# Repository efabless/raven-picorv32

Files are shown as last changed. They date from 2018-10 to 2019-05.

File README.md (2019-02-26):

Raven:  An ASIC implementation of the PicoSoC PicoRV32
===============================================================
Designed by efabless engineering, San Jose, CA

Overview
--------

The purpose of this repository is to provide a completely free
and open-source simulation environment for the Raven chip.  The
Raven chip itself can be found in the efabless IP catalog.  See
https://efabless.com (registration is required to view the IP
catalog.  Regitration is free and validation is not required to
view the catalog contents.  However, validation is required to
use the efabless design environments; e.g., to view the layout
of the raven chip on the Open Galaxy design platform).

The simulation environment matches the reference design in the
efabless IP catalog functionally, and can be used to write
software/firmware that will run on the Raven test board.

The requirements for simulating the Raven chip are:  iverilog
(iverilog.icarus.com), and the RISC-V gcc configured for the
RISC-V options used by the picoRV32 processor design.  The best
way to obtain the correct gcc cross-compiler is to install the
picoRV32 source from github
(https://github.com/cliffordwolf/picorv32).  The Makefile in
the picoRV32 repository automatically downloads and locally
installs the correct gcc cross-compiler.  In this repository,
it is necessary to change the path to gcc in verilog/Makefile
and verilog/*/Makefile to match the local installation.  Once
that is done, cd to the "verilog/" directory and run "make" to
run the simulation test suite.

Documentation on the memory mapping and the SPI slave interface
can be found in the "doc/" directory.

Summary
-------

Raven is using a very popular 32-bit RISC-V core (PicoRV32) developed by Clifford Wolf, a well-known open source champion. The core was previously proven with an FPGA implementation and Raven is the first SoC built with it. The system integrator is our own Tim Edwards, another champion in the open source domain. Included below is a 15s video showing the wakeup, key features and a link to high-level datasheet.

Raven is now published in our marketplace for designers and partner companies to clone and customize starting from a silicon-proven point. It is also published on the RISC-V Foundation’s directory of designs
(https://riscv.org/risc-v-cores)

RAVEN Block Diagram
-------------------

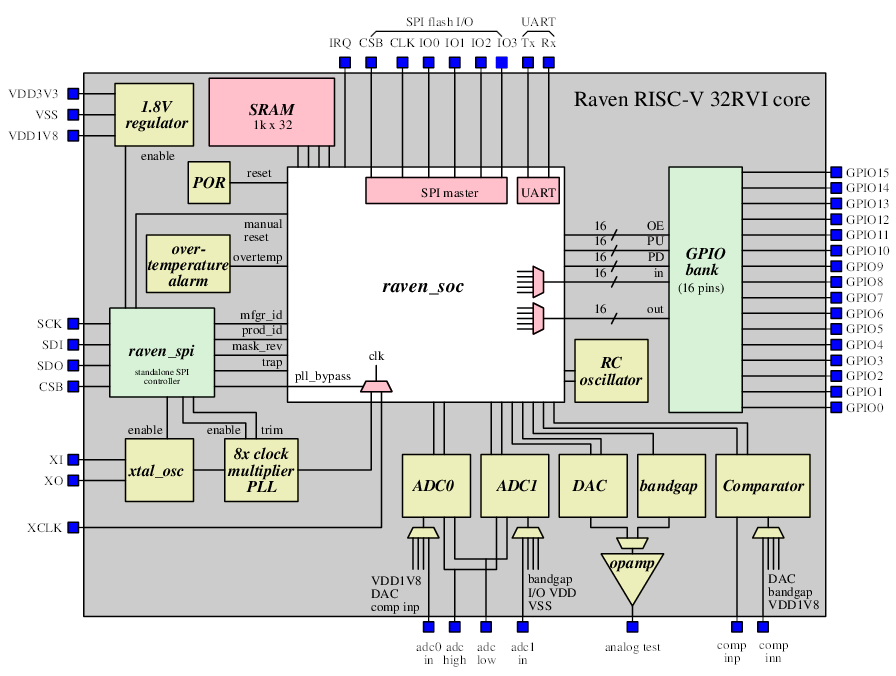
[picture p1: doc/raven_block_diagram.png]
RAVEN-PICORV32


Key Features
------------
* RISC-V CPU (PicoRV32)
* SRAM 32x1024
* 100 MHz clock rate
* Programmable clock source
* 16 channels GPIO
* 2 ADCs
* 1 DAC
* 1 Comparator
* Over-temperature alarm
* 100 kHz RC oscillator
* Programmable functions on GPIO outputs
* Programmable interrupts on GPIO inputs

High-level Datasheet 
---------------------
* https://ef.link/raven

Short Video showing initial wakeup
----------------------------------
* https://ef.link/raven3

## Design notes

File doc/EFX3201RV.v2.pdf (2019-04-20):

# EFX3201RV

## 32-bit RISC-V Microcontroller for Embedded Applications

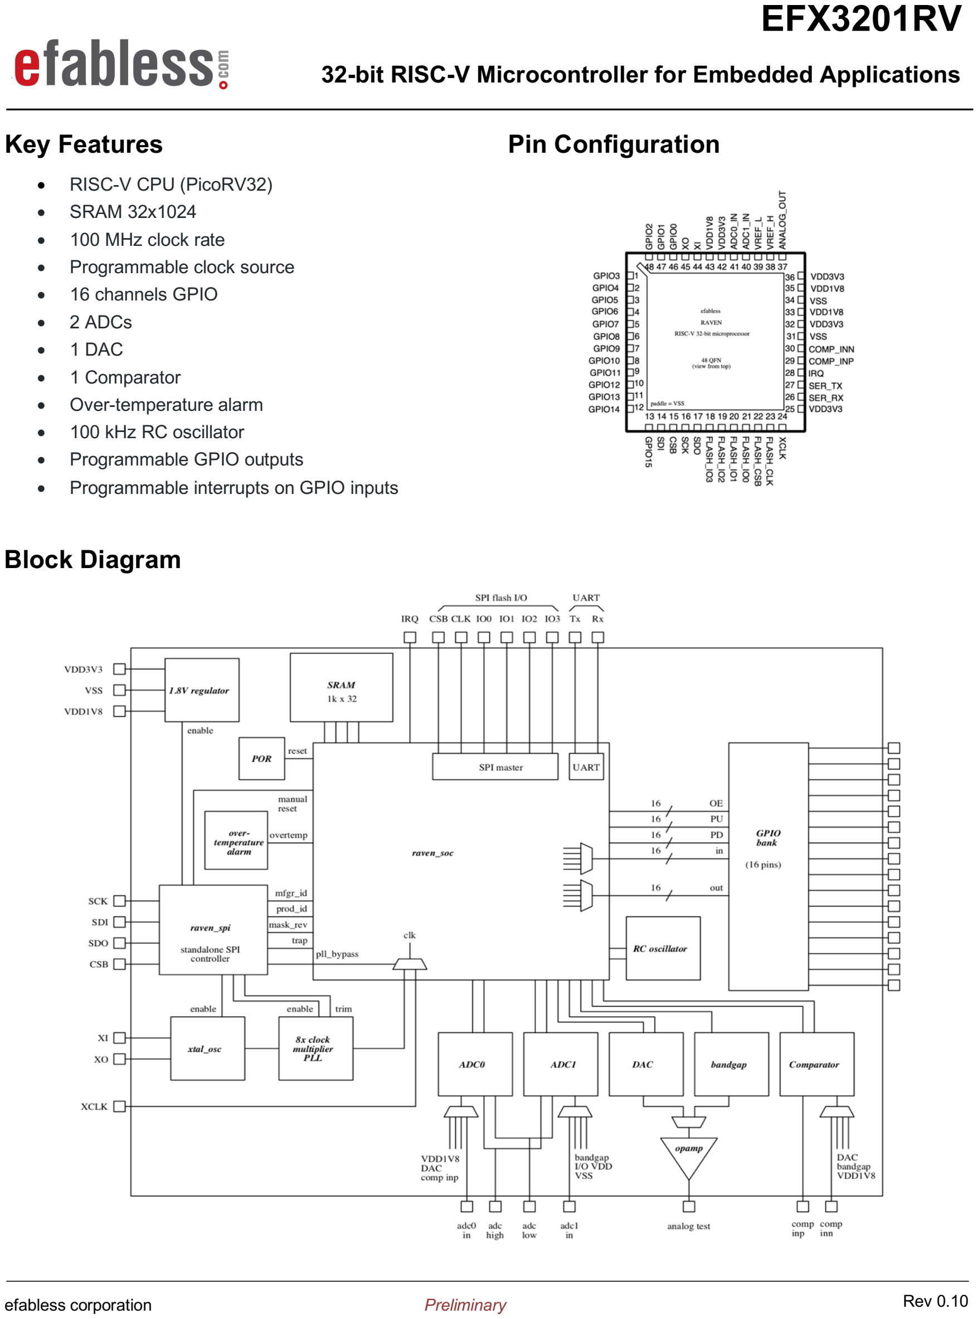
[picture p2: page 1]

efabless corporation | Preliminary

Rev 0.10

# Key Features

### - RISC-V CPU (PicoRV32) - SRAM 32x1024 - 100 MHz clock rate - Programmable clock source - 16 channels GPIO - 2 ADCs - 1 DAC - 1 Comparator - Over-temperature alarm - 100 kHz RC oscillator - Programmable GPIO outputs - Programmable interrupts on GPIO inputs

# Pin Configuration

# Block Diagram

# EFX3201RV

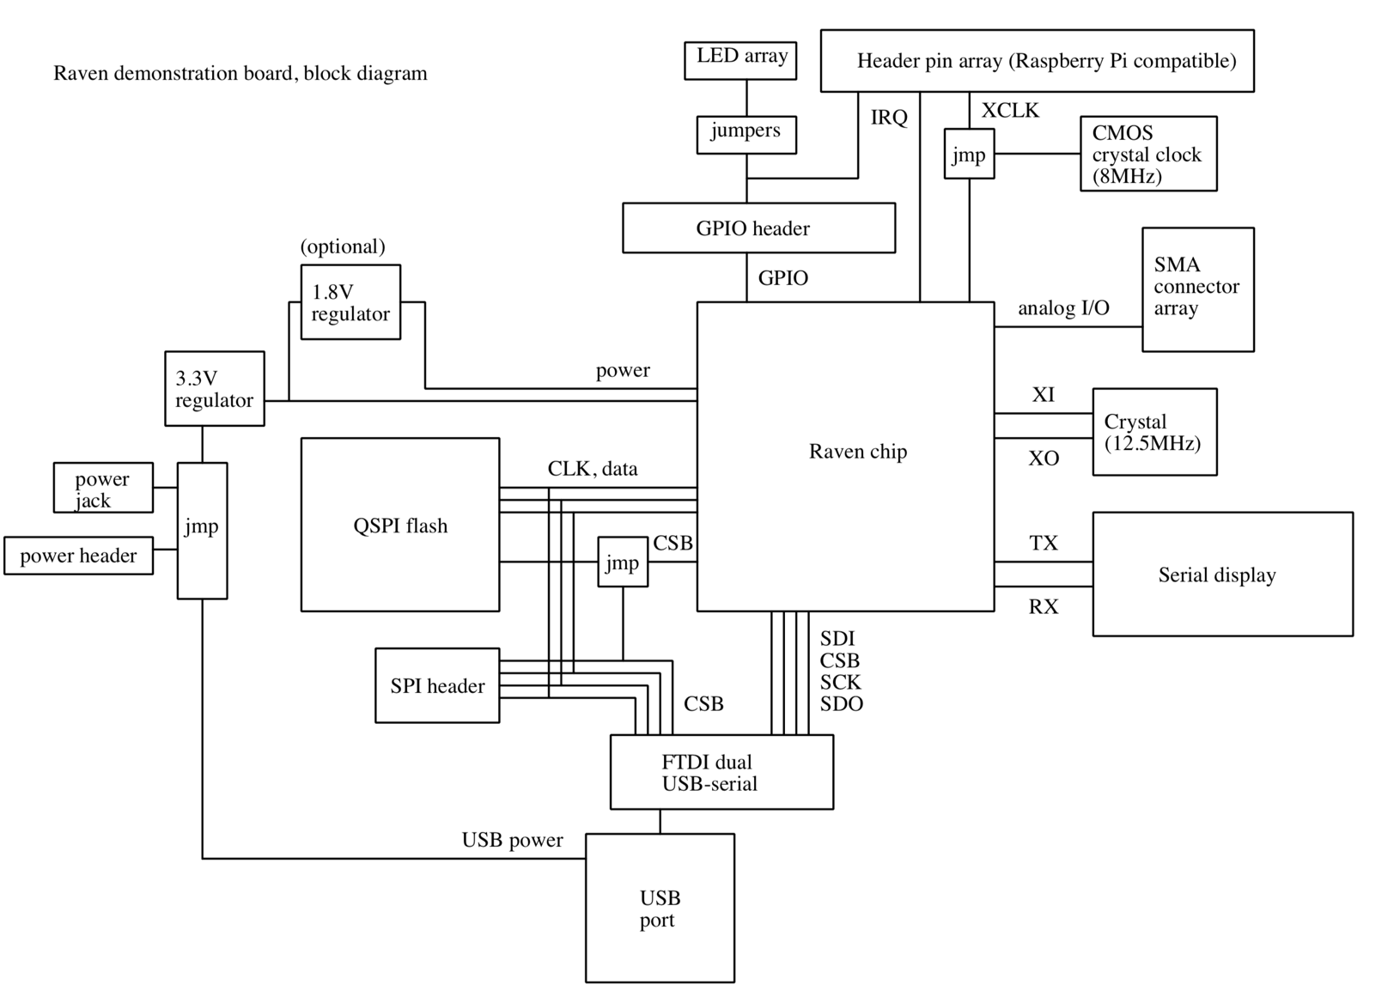
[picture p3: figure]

efabless corporation | Preliminary

## 32-bit RISC-V Microcontroller for Embedded Applications

Rev 0.10

# Raven Development Board

# For more information visit: https://github.com/efabless/raven-picorv32

# Features

1. Can be powered by external supplies, power jack, or USB.
2. Raven SPI programmed through FTDI via USB
3. SMA inputs to analog functions.
4. Serial display for text I/O from Raven chip.
5. Clock from crystal (100MHz onboard), external (8MHz) or data line
6. Match Raspberry Pi header pins with GPIO header pins
7. Split supplies if external 1.8V needed; otherwise chip is powered from 3.3V only. 3. Flash chip programmed through FTDI via USB

SPI flash: Cypress S25FL128 or similar ($2.42 each from Digi-Key). Use the 8-pin SOIC (4 data + clock, select, power, and ground). 3.3V.

Serial display: Use a SparkFun serial-enabled 16x2 LCD ($25), 3.3V, or the 20x4 SerLCD (also $25) (available from Digi-Key). Or the 20x2 SerLCD ($20).

FTDI: Use FT2232H (about $7 for the LQFP package from Digi-Key

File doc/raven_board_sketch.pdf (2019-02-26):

Raven demonstration board, block diagram

Raven chip

Serial display

TX

RX

FTDI dual
USB-serial

SDI
CSB
SCK
SDO

GPIO header

GPIO

USB
port
QSPI flash | CSB

CLK, data

CSB

jumpers

LED array

IRQ | XCLK | CMOS
| | crystal clock (8MHz)

Crystal
(12.5MHz)

XI

XO
power
jack

power header

3.3V
regulator

power

1.8V
regulator | analog I/O

SMA
connector
array

jmp

jmp

SPI header

jmp

USB power

Features:
1. Can be powered from external supplies, power jack, or USB.
2. Split supplies if external 1.8V needed; otherwise chip is powered from 3.3V only.
3. Flash chip programmed through FTDI via USB
4. Raven SPI programmed through FTDI via USB
5. SMA inputs to analog functions.
6. Serial display for text I/O from Raven chip.
7. Clock from crystal (100MHz onboard), external (8MHz) or data line (slow)
8. Match Raspberry Pi header pins with GPIO header pins

SPI flash: Cypress S25FL128 or similar ($2.42 each from Digi-Key). Use the 8-pin SOIC (4 data + clock, select, power, and ground). 3.3V.

FTDI: Use FT2232H (about $7 for the LQFP package from Digi-Key)

Serial display: Use a SparkFun serial-enabled 16x2 LCD ($25), 3.3V, or the 20x4 SerLCD (also $25) (available from Digi-Key). Or the 20x2 SerLCD ($20).

(optional)

Header pin array (Raspberry Pi compatible)

Raspberry-Pi compatibility GPIO header (3.3V)

5V

5V

From USB or power jack

VDD3V3

N/C (I2C)

N/C (I2C) | Ground
| TX
| RX

EXTCLK

Ground

GPIO0 | GPIO1

GPIO2

GPIO3

VDD3V3

SDI

SDO

SCK

Ground

Ground

CSB (Raven)

N/C (2nd SPI CSB)

N/C (I2C EEPROM)

Ground

Ground

Ground

Ground

GPIO4

GPIO5

GPIO6

GPIO7

GPIO8

GPIO9

GPIO10

GPIO11

GPIO13

GPIO14

GPIO15

GPIO12

N/C (I2C EEPROM)

NOTES:

Generally, the GPIO line up with similar channels on the Raspberry Pi board. The GCLK on the Pi is connected to the Raven external clock input. The I²C lines are not connected. The Raven SPI is connected to the Pi SPI lines.

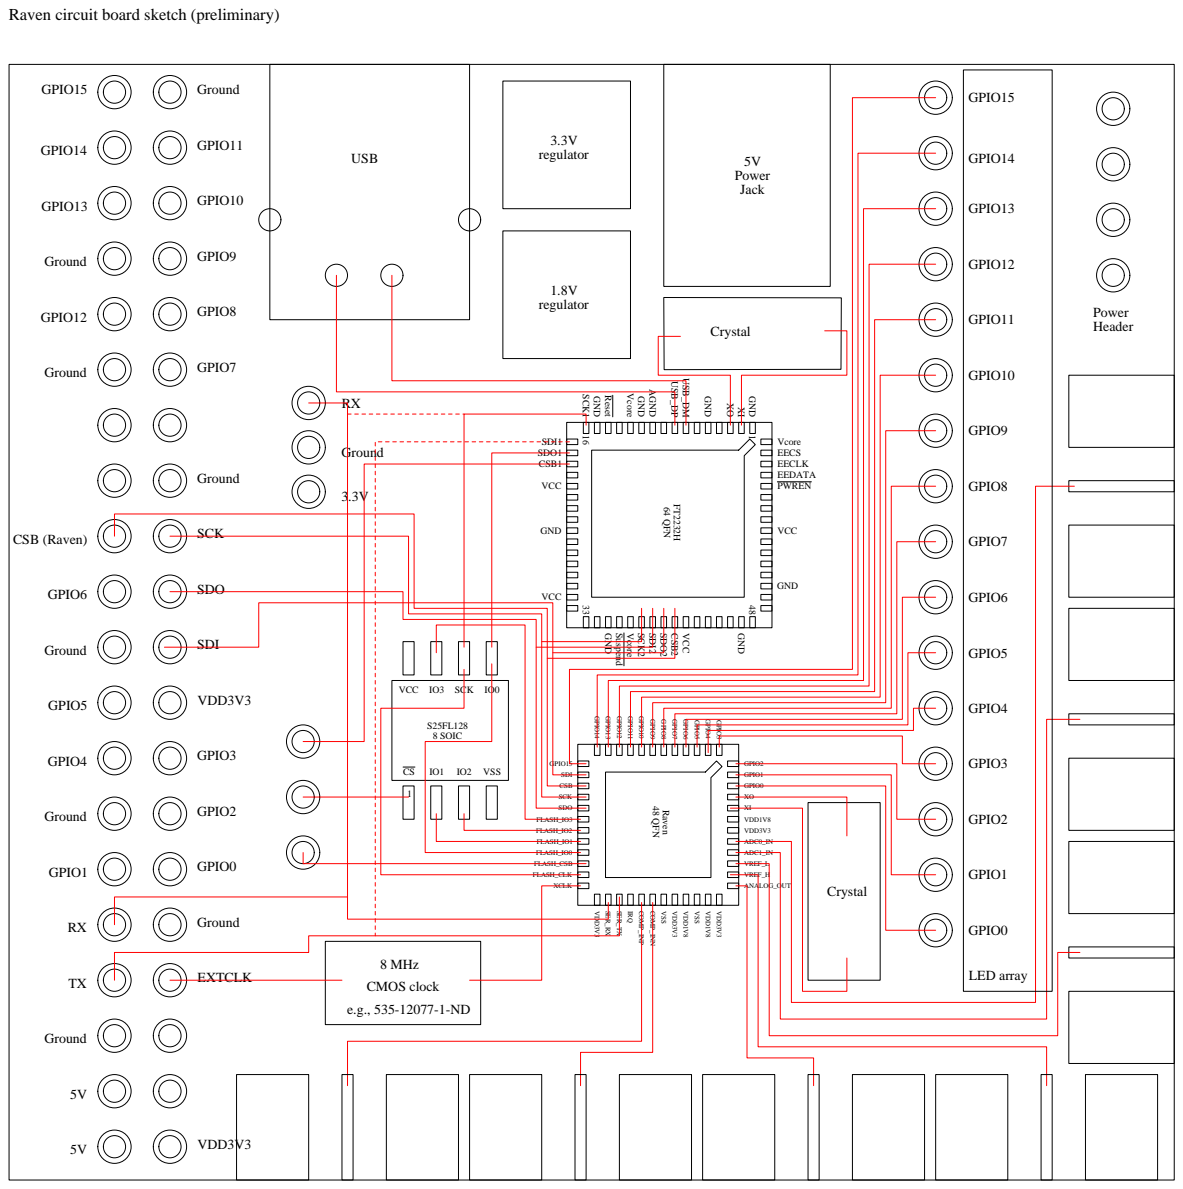
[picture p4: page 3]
Raven; 48 QFN; GPIO15 SDI CSB SCK SDO FLASH_IO3 FLASH_IO2 FLASH_IO1 FLASH_IO0 FLASH_CSB FLASH_CLK XCLK; VDD3V3; SER_RX; SER_TX; IRQ; COMP_INP; COMP_INN; VSS; VDD1V8; GPIO2 GPIO1 GPIO0 XO XI VDD1V8 VDD3V3 ADC0_IN ADC1_IN VREF_L VREF_H ANALOG_OUT; GPIO9; GPIO8; GPIO7; GPIO6; GPIO5; GPIO4; GPIO3; GPIO14; GPIO13; GPIO12; GPIO11; GPIO10; EXTCLK; Ground; GPIO0; GPIO2; SDI; SDO; SCK; GPIO1; CSB (Raven); GPIO15; 64 QFN; 1 GND; GND; VCC; AGND; Reset; EECS EECLK EEDATA PWREN; Suspend; SCK1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

Raven circuit board sketch (preliminary)

Vcore Vcore Vcore

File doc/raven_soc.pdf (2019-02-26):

Raven SoC—A PicoSoC implementation in X-Fab XH018

Raven Memory Mapped I/O

0x02 00 00 00

Address (bytes) | Function
0x02 00 00 04 | UART clock divider select (system clock freq. / baud rate)
0x02 00 00 08 | UART data (returns 0xffffffff if receiver buffer is empty)

SPI master config

0x00 00 00 00 | Flash SPI / overlaid SRAM (1k words) start of memory block
0x00 10 00 00 | Reset vector
0x01 00 00 00 | Flash SPI start of memory block

0x03 00 00 00

bit 31 MEMIO enable (reset = 1) 0 = bit-bang mode bit 22 DDR enable
bit 21 QSPI enable
bit 20 CRM enable
bits 19-16 Read latency cycles
bits 11-8 I/O output enable bits (bit bang mode) bit 5 Chip select line (bit bang mode)
bit 4 Serial clock line (bit bang mode)
bits 3-0 Data bits (bit bang mode)

GPIO input/output data (lower 16 bits)
0x03 00 00 04 | GPIO input enable (1 = input, 0 = output)
0x03 00 00 08 | GPIO pullup enable (1 = pullup, 0 = none)
0x03 00 00 0c | GPIO pulldown enable (1 = pulldown, 0 = none)
0x03 00 00 10 | ADC0 enable (low bit 1 = enabled, 0 = disabled)
0x03 00 00 14 | ADC0 data (10 bits) read-only
0x03 00 00 18 | ADC0 done (low bit 1 = done, 0 = busy) read-only
0x03 00 00 1c | ADC0 start conversion (low bit 1 = convert, 0 = reset)
0x03 00 00 20 | ADC0 clock source (low 2 bits)
| 0 =
| 1 =
| 2 =
| 3 =
0x03 00 00 24 | ADC0 input source (low 2 bits)
| 0 =
| 1 =
| 2 =
| 3 =
0x03 00 00 30 | ADC1 enable (low bit 1 = enabled, 0 = disabled)
0x03 00 00 34 | ADC1 data (10 bits) read-only
0x03 00 00 38 | ADC1 done (low bit 1 = done, 0 = busy) read-only
0x03 00 00 3c | ADC1 start conversion (low bit 1 = convert, 0 = reset)
0x03 00 00 40 | ADC1 clock source (low 2 bits)
| 0 =
| 1 =
| 2 =
| 3 =
0x03 00 00 44 | ADC1 input source (low 2 bits)
| 0 =
| 1 =
| 2 =
| 3 =

external pin
VDD1V8
DAC
comparator P input

external pin

VDD3V3
VSS

bandgap

RC osc
SPI SCK
Xtal clock
XCLK pin

RC osc
SPI SCK
Xtal clock
XCLK pin

Program to run starts here.

16 bits of general-purpose digital

ADC can be manually clocked via the SPI SCK or XCLK pins, or automatically clocked at the rate of the crystal or the RC oscillator.

ADC normally reads the value of an external pin, but for testing can be set to read the internal values of the core power supply, DAC, or the comparator P input pin.

ADC can be calibrated by setting input to the 3.3V power supply and ground, and can be used to read the bandgap voltage.

Address (bytes) | Function
0x03 00 00 54 | DAC value (10 bits)
0x03 00 00 50 | DAC enable (low bit 1 = enabled, 0 = disabled)
0x03 00 00 60 | Comparator enable (low bit 1 = enabled, 0 = disabled)
0x03 00 00 64 | Comparator N input source (low 2 bits)
| 0 = 1 = 2 = 3 =
0x03 00 00 68 | Comparator P input source (low 2 bits)
| 0 = 1 = 2 = 3 =
0x03 00 00 6c | Comparator output destination (low 2 bits)
| 0 = 1 =
0x03 00 00 70 | RC oscillator enable (low bit, 1 = enabled, 0 = disabled)
0x03 00 00 74 | RC oscillator output destination (low 2 bits)
| 0 =
| 1 =
| 2 =
| 3 =
0x03 00 00 80 | SPI configuration byte (low 8 bits) (read-only)
| Value currently fixed at zero
0x03 00 00 84 | SPI master enables (low 2 bits) (read-only)
| bit 0 = 1.8V regulator enable
| bit 1 = Crystal oscillator enable
0x03 00 00 88 | SPI PLL config (low 7 bits) (read-only)
| bit 0 = PLL current bias enable
| bit 1 = PLL VCO enable
| bit 2 = PLL CP enable
| bits 3-6 = PLL frequency trim
0x03 00 00 8c | SPI manufacturer ID (low 12 bits) ( = 0x0456) (read-only)
0x03 00 00 90 | SPI product ID (low 8 bits) ( = 0x02) (read-only)
0x03 00 00 94 | SPI mask revision (low 4 bits) ( = 0x00) (read-only)
0x03 00 00 a0 | Crystal output destination (low 2 bits)
| 0 =
| 1 =
| 2 =
| 3 =
0x03 00 00 98 | SPI PLL bypass mode (low bit) (read-only)

external pin
DAC
bandgap
VDD1V8

external pin

2 =
3 =

GPIO(0)
GPIO(1)
IRQ(9)

none

GPIO(2)
GPIO(3)

none

GPIO(4)

GPIO(5)
GPIO(6)
GPIO(7)

none

DAC
bandgap
VDD1V8

Raven SoC—A PicoSoC implementation in X-Fab XH018

Raven Memory Mapped I/O (continued)

Comparator can have one input set to a known internal value, either the DAC output, the bandgap voltage, or the core supply voltage.

Comparator output can be seen directly
on GPIO 0 or 1, or used to trigger CPU interrupt IRQ 9. GPIOs 0 and 1 cannot be used for general-purpose I/O when selected for comparator output.

RC oscillator output can be passed directly to GPIO 2, 3, or 4. These cannot be used as general-purpose I/O when selected for RC oscillator output.

Most bits of the SPI register map are mirrored to memory locations and can be read by the CPU. These bits are read-only and cannot be modified.

The crystal oscillator clock (before the PLL) can be coupled to any of GPIO pins 5, 6, or
7. These GPIOs cannot be used as general-purpose I/O when selected for crystal oscillator clock output.

Address (bytes) | Function
0x03 00 00 a4 | PLL clock output destination (low 2 bits) 0 = 1 = 2 = 3 =
0x03 00 00 a8 | Trap output destination (low 2 bits) 0 = 1 = 2 = 3 =
0x03 00 00 b0 | IRQ 7 input source (low 2 bits) 0 = 1 = 2 = 3 =
0x03 00 00 b4 | IRQ 8 input source (low 2 bits) 0 = 1 = 2 = 3 =
0x03 00 00 c0 | Analog output select (low bit) 0 = DAC 1 =

0x03 00 00 c4

0x03 00 00 c8 | Analog output enable (low bit, 1 = enabled, 0 = disabled) Analog output bias enable (low bit, 1 = enabled, 0 = disabled)
0x03 00 00 d0 | Bandgap enable (low bit, 1 = enabled, 0 = disabled) bandgap

none
GPIO(8)
GPIO(9)
GPIO(10)

none
GPIO(11)
GPIO(12)
GPIO(13)

GPIO(0)

none

none

GPIO(1)
GPIO(2)

GPIO(3)
GPIO(4)
GPIO(5)

Raven SoC—A PicoSoC implementation in X-Fab XH018

Raven Memory Mapped I/O (continued)

The PLL clock (crystal oscillator clock multiplied up by 8 times) can be viewed on any of GPIO 8, 9, or 10. These GPIOs cannot be used as general-purpose I/O when selected for PLL clock output. It is unlikely that a full-speed (100MHz) clock will be able to toggle the GPIO at full swing, but a slower clock (5 MHz crystal / 40 MHz core clock) should have a proper output.

The CPU fault state (trap) can be viewed at GPIO 11, 12, or 13, as a way to monitor the CPU trap externally.

The GPIO inputs can be used as IRQ event sources and passed to the CPU through IRQ channels 7 and 8. When used as IRQ sources, the corresponding GPIO channel must be first configured as an input.

A single op-amp configured as an analog buffer can be selected to mirror the analog DAC output or the bandgap output.

0x03 00 00 e0 | Over-temperature alarm enable (low bit, 1 = enabled, 0 = disabled)
0x03 00 00 e4 | Over-temperature value (low bit, read-only)
0x03 00 00 e8 | Over-temperature destination (low 2 bits)
| 0 = 1 = 2 = 3 = none GPIO(14) GPIO(15) IRQ(10) The over-temperature sensor triggers at 133 degrees C. It can be viewed at GPIO 14 or 15, or used as an IRQ source to the CPU.

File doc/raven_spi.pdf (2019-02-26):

msb | lsb
Register
Address
0x00 | SPI status and control | unused/undefined for now.
0x01 | mask revision (= 0x0) | manufacturer_ID[11:8] (= 0x4) | read-only
0x02 | manufacturer_ID[7:0] (currently undefined, = 0x56) | | read-only
0x03 | product_ID (= 0x02) | | read-only
0x04 | enable | 1.8V regulator enable | PLL VCO enable | PLL CP enable | PLL trim[3:0] xtal osc. | default 0xf0
0x05 | unused | PLL bypass | default 0x00
0x06 | unused | CPU IRQ | default 0x00
0x07 | unused | CPU reset | default 0x00
0x08 | unused | CPU trap | read-only
0x09 | undefined, use TBD | | all undefined registers read 0x00
7 | 6 | 5 | 4 | 3 | 2 | 1 | 0 | comments

Raven rev 0 SPI register definition:

January 4, 2018

NOTES: These registers access values that are impossible to reach using the CPU.
(1) The crystal oscillator drives the CPU clock, so it cannot be turned on and off from inside the CPU. By default it is enabled.
(2) The 1.8V regulator supplies power to the CPU, so it cannot be disabled from the CPU. By default it is enabled.
(3) The PLL generates the high-speed clock from the low-speed crystal, acting as an 8x clock multiplier. By default it is enabled, and has zero trim.
(4) PLL bypass allows the CPU to completely bypass the crystal and PLL and be driven directly by a signal on the XCLK pin.
(5) CPU IRQ is a dedicated interrupt that can be applied to the CPU from the SPI for test purposes.
(6) CPU reset allows the CPU to be reset independently of the power-on-reset circuit.
(7) CPU trap is the fault signal from the CPU. If raised, then the CPU has encountered a bad instruction and has stopped.

Under normal working conditions, the SPI should not need to be accessed unless it is to adjust the clock speed of the CPU. All other functions are purely for test and debug.

All values in the SPI registers are exported to the CPU and can be viewed (read-only) in memory-mapped space (see the memory map documentation).

Errata (updated February 2019):

1. The bits of register 0x04 read as shown above but must be written in the reverse order of bits.
2. The PLL CP enable is nonfunctional as the corresponding output bit in the SPI block is hard-coded to force logic 1 always.

SPI protocol definition

Table 1: Command words
00000000 | No operation
10000000
01000000 | Write in streaming mode
| Read in streaming mode
11000000 | Simultaneous Read/Write in streaming mode
10nnn000

All input is in groups of 8 bits. Each byte is input msb first.

The first transferred byte is the command word, interpreted according to Table 1 below.

CSB pin must be low to enable an SPI transmission. Data are clocked by pin SCK, with data valid on the rising edge of SCK. Output data are received on the SDO line. SDO is held high-impedance when CSB is high and at all times other than the transfer of data bits on a read command. SDO outputs become active on the falling edge of SCK, such that data are written and read on the same SCK rising edge.
After CSB is set low, the SPI is always in the "command" state, awaiting a new command.

Addresses are read in sequence from lower values to higher values.
Therefore groups of bits larger than 8 should be grouped such that the lowest bits are at the highest address. Any bits additional to an 8-bit boundary should be at the lowest address.
Data are captured from the register map in bytes on the falling edge of the last SCK before a data byte transfer. Multi-byte transfers should ensure that data do not change between byte reads.

01nnn000
11nnn000

Write in n-byte mode (up to 7 bytes).
Read in n-byte mode (up to 7 bytes).
Simultaneous Read/Write in n-byte mode (up to 7 bytes).

All other words are reserved and act as no-operation if not defined by the SPI slave module.

The two basic modes of operation are "streaming mode" and "n-byte mode". In "streaming mode" operation, data are sent or received continuously, one byte at a time, with the internal address incrementing for each byte. Streaming mode operation continues until CSB is raised to end the transfer.

Every command sequence requires one command word (8 bits) followed by one address word (8 bits) followed by one or more data words (8 bits each), according to the data transfer modes defined below.

In "n-byte mode" operation, the number of bytes to be read and/or written is encoded in the command word, and may have a value from 1 to 7 (note that a value of zero implies streaming mode). After n bytes have been read and/or written, the SPI returns to waiting for the next command. No toggling of CSB is required to end the command or to initiate the following command.

Raven rev0 efabless, inc.

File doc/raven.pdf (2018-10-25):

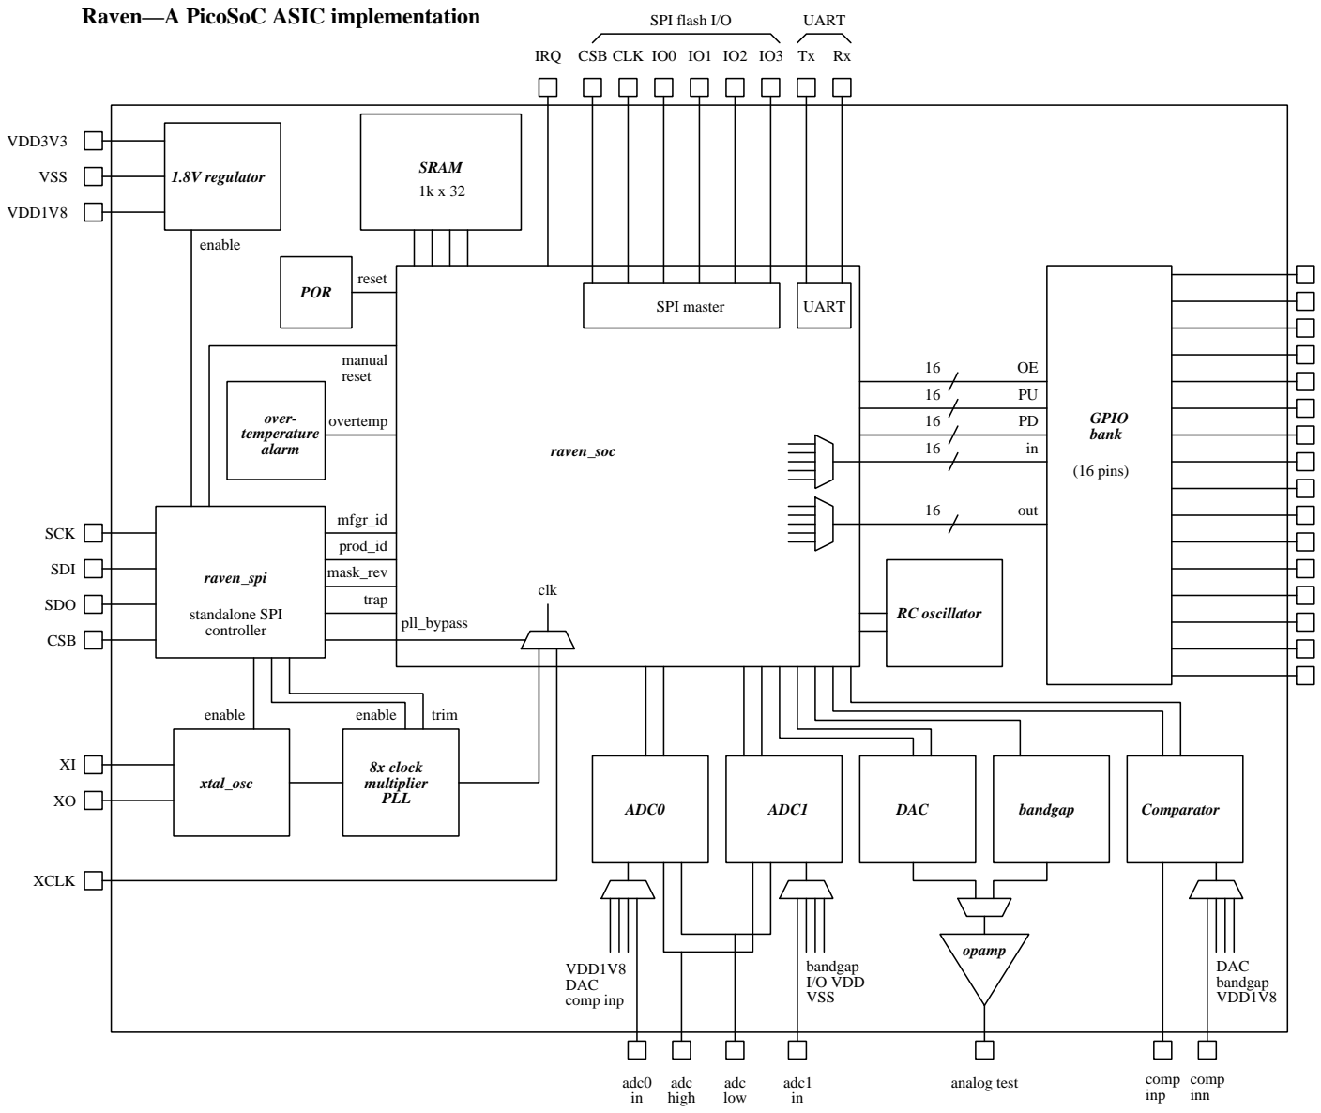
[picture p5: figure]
Raven—A PicoSoC ASIC implementation; raven_soc; GPIO bank; out; (16 pins); raven_spi; SCK; SDI; SDO; CSB; xtal_osc; 1.8V regulator; VDD3V3; VDD1V8; VSS; 8x clock multiplier PLL; XCLK; pll_bypass; clk; enable; trim; mfgr_id; prod_id; mask_rev; over- temperature alarm; overtemp; ADC0; ADC1; DAC; Comparator; RC oscillator; POR; reset; manual reset; bandgap; opamp; adc0; analog test; adc high; adc low; adc1 in; comp inp; comp inn; VDD1V8 DAC comp inp; bandgap I/O VDD VSS; DAC bandgap VDD1V8; IRQ; trap; SRAM; SPI flash I/O; UART; standalone SPI controller; CSB CLK IO0 IO1 IO2 IO3; SPI master

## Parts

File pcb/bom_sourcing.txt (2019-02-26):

eFabless Raven PicoRV32 development/demonstration board
---------------------------------------------------------
U1	efabless Raven PicoRV32
	QFN48
	(custom ASIC, provided)

U2	FT2232H		Dual USB/serial interface driver
	FTDI
	64 LQFP package
	Digi-key 768-1024-1-ND		$6.71 (total $6.71)

U3	93LC46 SPI EEPROM
	MicroChip Technology
	8 TSSOP
	Digi-key 93LC46B-I/ST-ND	$0.27	(total $0.27)

U4	S25FL128
	128M SPI Flash SRAM
	Cypress Semiconductor
	8 SOIC
	Digi-key 428-4051-ND		$2.46	(total $2.46)

U5	AP7333-33SAG-7	3.3V LDO, 0.3A
	Diodes, Inc. 
	SOT23-3
	Digi-key AP7333-33SAG-7DICT-ND	$0.48	(total $0.48)

U6	AP7333-18SAG-7	1.8V LDO, 0.3A
	Diodes, Inc. 
	SOT23-3
	Digi-key AP2125N-1.8TRG1DICT-ND  $0.49	(total $0.49)
	NOTE:  This part is optional.

X1	Crystal, 12MHz, 18pF
	ECS, Inc.
	SMD HC-49USX CSM-7X ECS-120-18-5PX-TR
	Digi-key XC1289CT-ND	 	$0.21	(total $0.21)

X2	Crystal 12.5MHz, 18pF
	TXC Corp.
	Crystal 12.5MHz 18pF SMD
	Digi-key 887-2416-1-ND		$0.43	(total $0.43)

X3	CMOS Crystal oscillator, 8MHz
	Abrocon LLC ASCO-8.000MHZ-EK-T3
	Digi-key 535-12077-1-ND		$1.86	(total $1.86)

J1	4x2 header, 0.1" spacing
	(see below *)

J2-J5	3-pin headers, 0.1" spacing (4x)
	(see below *)

J6	4-pin connector
	Molex, Inc. 0022232041  4 position 0.1" spacing header
	Digi-key WM4202-ND		$0.37	(total $0.37)
	
J7	2.5mm power jack
	CUI, Inc.  PJ002B
	Digi-key CP-002B-ND	 	$0.92	(total $0.92)

J8	USB type B 4-position connector
	TE Connectivity 292304-1
	Digi-key A31725-ND	 	$1.92	(total $1.92)

J9	17x2 test header, 0.1" spacing, unpopulated
	(no component installed)

J10	20x2 header, 0.1" spacing
	(see below *)

J11-J12	3-pin headers, 0.1" spacing (2x)

*	All headers from one break-off header 2x36 position (gold)
	3M 961272-6404-AR
	Digi-key 3M9466-72-ND		$4.60	(total $4.60)

	(assembly pin count: 2x20 (1), 2x4 (1), 1x3 (6) 1x2 (1) 1x1 (2))

D2-D17	LEDs, 0805 SMT, green
	Lite-On Inc.
	Digi-key 160-1423-1-ND (Green)  $0.05	(total $0.80)

D1	LEDs, 0805 SMT, red
	Lite-On Inc.
	Digi-key 160-1415-1-ND (Red)  $0.05	(total $0.05)

D0,D18	LEDs, 0805 SMT, yellow
	Lite-On Inc.
	Digi-key 160-1416-1-ND (Yellow)	$0.05	(total $0.10)
	
C0	4.7uF electrolytic radial capacitor
	## (Note:  the part below was unavailable in small quantities)
	## Panasonic ECA-1HM4R7I Digi-key  P10424TB-ND
	UPS1H4R7MDD1TD
	Digi-key 493-11322-1-ND		$0.28	(total $0.28)

C1	22uF 1210 SMT capacitor
	AVX NOJB226M006RWJ
	Digi-key 478-1823-1-ND		$0.16	(total $0.16)

C2-C3	4.7uF 1210 SMT capacitor
	Kemet C1210C485K3PACTU
	Digi-key 399-3146-1-ND		$0.81	(total $1.62)

C4-C7	100nF 0603 SMT capacitor (corrected---was listed as 0805)
	Kemet C0603C104K3RACTU  (corrected)
	Digi-key 399-1281-1-ND		$0.16	(total $0.80)

C8-C11	18pF 0603 SMT capacitor		
	Kemet C0603C180K3GACTU	(corrected)
	Digi-key 399-9019-1-ND		$0.31	(total $1.24)

C12	100nF 0805 SMT capacitor
	Kemet C0805C104K3RACTU
	Digi-key 399-1168-1-ND		$0.10	(total $0.10)

C13	3.3uF 0805 SMT capacitor
	Kemet C0805C335K9PACTU
	Digi-key 399-3130-1-ND		$0.60	(total $0.60)

R1	12kOhm 0603 SMT resistor
	Panasonic
	Digi-key P12KGCT-ND		$0.10	(total $0.10)

R2	1kOhm 0603 SMT resistor
	Panasonic
	Digi-key P1.0KGCT-ND		$0.10	(total $0.10)

R3	4.7kOhm 0603 SMT resistor
	Panasonic
	Digi-key P4.7KGCT-ND		$0.10	(total $0.10)

R4	10kOhm 0603 SMT resistor
	Panasonic
	Digi-key P10KGCT-ND		$0.10	(total $0.10)

R6-R8	10kOhm 0603 SMT resistor
	Panasonic
	Digi-key P10KGCT-ND		$0.10	(total $0.30)

R9	2.2kOhm 0603 SMT resistor
	Panasonic
	Digi-key P2.2KGCT-ND		$0.10	(total $0.10)

R10-R28 62Ohm 0603 SMT resistor
	Panasonic
	Digi-key P62GCT-ND		$0.10	(total $1.90)

(J11)	Serial LCD 16x4 character
	SparkFun Electronics LCD-14074
	Digi-key 1568-1905-ND		$25.00	(total $25.00)
	(Soldered to J11 posts)
	Not part of assembly.

--	SMA side-mount (8x)
	Emerson 142-0701-801
	Digi-key J502-ND   		$5.10 (total $40.80)
	Not part of assembly.

--	Shunts 0.1" (10x) (optional)
	3M Corp. QPC02SXGN-RC
	Digi-key S9337-ND		$0.10 each (total $1.00)
	Not part of assembly.

Assorted other parts:  Screws, standoffs:
	Not part of assembly.

	Board component purchase total: $94.61

Board price:				$?  	(with 5 boards ordered)
					-------
					$?

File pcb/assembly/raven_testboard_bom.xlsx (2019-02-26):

Name of the file:raven-testboard-bom.xlsx
Date:21-DEC-2018, 11:19 AM EST
eFabless raven test and development board
ITEM# | Designators | Sierra quantity | Description | MFG. | Manufacturing Part | Vendor Name | Vendor Part | Unit price | Total | DEVICE TYPE! | DEVICE SUBTYPE1! | Lead Content! | ROHS Info! | Vendor Description! | Alternate MPN! | Alternate Vendor Description! | Vendor! | Vendor Part#! | Remarks for Customer! | Customer Feedback!
1 | U1 | 1 | Custom ASIC RISC-V microcontroller | efabless | Raven PicoRV32 | N/A | N/A | N/A | N/A | QFN48 |  | Lead Free | RoHS Compliant | Custom device supplied by customer, shipped from packaging vendor.
2 | U2 | 1 | USB/serial interface driver | FTDI | FT2232H | Digi-key | 768-1024-1-ND | $6.71 | $6.71 | 64 LQFP |  | Lead Free | RoHS Compliant | IC USB HS DUAL UART/FIFO 64-LQFP
3 | U3 | 1 | SPI EEPROM | Microchip | 93LC46 | Digi-key | 93LC46B-I/ST-ND | $0.27 | $0.27 | 8 TSSOP |  | Lead Free | RoHS Compliant | IC EEPROM 1K SPI 2MHZ 8TSSOP
4 | U4 | 1 | 128M SPI Flash SRAM | Cypress Semiconductor | S25FL128 | Digi-key | 428-4051-ND | $2.46 | $2.46 | 8 SOIC |  | Lead Free | RoHS Compliant | IC FLASH 128M SPI 133MHZ 8SOIC
5 | U5 | 1 | 3.3V voltage regulator (LDO), 0.3A | Diodes, Inc. | AP7333-33SAG-7 | Digi-key | AP7333-33SAG-7DICT-ND | $0.48 | $0.48 | SOT23-3 |  | Lead Free | RoHS Compliant | IC REG LINEAR 3.3V 300MA SOT23-3
6 | U6 | 1 | 1.8V voltage regulator (LDO), 0.3A | Diodes, Inc. | AP2125N | Digi-key | AP2125N-1.8TRG1DICT-ND | $0.49 | $0.49 | SOT23-3 |  | Lead Free | RoHS Compliant | IC REG LINEAR 1.8V 300MA SOT23-3
7 | X1 | 1 | Crystal, 12MHz, 18pF | ECS, Inc. | SMD HC-49USX CSM-7X ECS-120-18-5PX-TR | Digi-key | XC1289TR-ND | $0.21 | $0.21 | HC-49/US |  | Lead Free | RoHS Compliant | CRYSTAL 12.0000MHZ 18PF SMD
8 | X2 | 1 | Crystal, 12.5MHz, 18pF | TXC, Inc. | 9C-12.500MAAJ-T | Digi-key | 887-2416-1-ND | $0.43 | $0.43 | HC-49/S |  | Lead Free | RoHS Compliant | CRYSTAL 12.5000MHZ 18PF SMD
9 | X3 | 1 | CMOS Crystal oscillator, 8MHz | Abrocon LLC | ASCO-8.000MHZ-EK-T3 | Digi-key | 535-12077-1-ND | $1.86 | $1.86 | 4-SMD | No lead | Lead Free | RoHS Compliant | XTAL OSC XO 8.0000MHZ CMOS SMD
10 | J1 | 1 | 4x2 header, 0.1" spacing | see row 26 |  |  |  |  |  | Thru-hole |  | Lead Free | RoHS Compliant
11 | J2-J5, J11-J12 | 6 | 3-pin headers, 0.1" spacing | see row 26 |  |  |  |  |  | Thru-hole |  | Lead Free | RoHS Compliant
12 | J6 | 1 | 4-pin connector, 0.1'' spacing | Molex, Inc. | 22232041 | Digi-key | WM4202-ND | $0.37 | $0.37 | Thru-hole |  | Lead Free | RoHS Compliant | CONN HEADER VERT 4POS 2.54MM
13 | J7 | 1 | 2.5mm power jack | CUI, Inc. | PJ002B | Digi-key | CP-002B-ND | $0.92 | $0.92 | Thru-hole |  | Lead Free | RoHS Compliant | CONN PWR JACK 2.5X5.5MM SOLDER
14 | J8 | 1 | USB type B 4-position connector | TE Connectivity | 292304-1 | Digi-key | A31725-ND | $1.92 | $1.92 | Thru-hole |  | Lead Free | RoHS Compliant | CONN RCPT USB2.0 TYPEB 4POS R/A
15 | J9 | 0 | 17x2 header, 0.1" spacing, UNPOPULATED | N/A
16 | J10 | 1 | 20x2-pin header, 0.1" spacing. All headers from one break-off header 2x36 position (gold) | 3M | 961272-6404-AR | Digi-key | 3M9466-72-ND | $4.60 | $4.60 | Thru-hole |  | Lead Free | RoHS Compliant | CONN HEADER VERT 72POS 2.54MM
17 | D2-D17 | 16 | LED 0805 SMD green | Lite-On Inc. | LTST-C171GKT | Digi-key | 160-1423-2-ND | $0.05 | $0.80 | 0805 SMD |  | Lead Free | RoHS Compliant | LED GREEN CLEAR CHIP SMD
18 | D1 | 1 | LED 0805 SMD red | Lite-On Inc. | LTST-C170KRKT | Digi-key | 160-1415-2-ND | $0.05 | $0.80 | 0805 SMD |  | Lead Free | RoHS Compliant | LED RED CLEAR SMD
19 | D0,D18 | 2 | LED 0805 SMD yellow | Lite-On Inc. | LTST-C170KSKT | Digi-key | 160-1416-2-ND | $0.05 | $0.10 | 0805 SMD |  | Lead Free | RoHS Compliant | LED YELLOW CLEAR SMD
20 | C0 | 1 | 4.7uF electrolytic radial capacitor | Panasonic | ECA-1HM4R7I | Digi-key | P10424TB-ND | $0.04 | $0.04 | Thru-hole | Can, Radial | Lead Free | RoHS Compliant | CAP ALUM 4.7UF 20% 50V RADIAL
21 | C1 | 1 | 22uF 1210 SMD capacitor | ABX | NOJB226M006RWJ | Digi-key | 478-1823-2-ND | $0.16 | $0.16 | 1210 SMD |  | Lead Free | RoHS Compliant | CAP NIOB OXID 22UF 20% 6.3V 1210
22 | C2-C3 | 2 | 4.7uF 1210 SMD capacitor | Kemet | C1210C485K3PACTU | Digi-key | 399-3146-1-ND | $0.81 | $0.81 | 1210 SMD |  | Lead Free | RoHS Compliant | CAP CER 4.7UF 25V X5R 1210
23 | C4-C7, C12 | 5 | 100nF 0603 SMD capacitor | Kemet | C0603C104K3RACTU | Digi-key | 399-1281-1-ND | $0.16 | $0.80 | 0603 SMD |  | Lead Free | RoHS Compliant | CAP CER 0.1UF 25V X7R 0603
24 | C8-C11 | 4 | 18pF 0603 SMD capacitor | Kemet | C0603C180K3GACTU | Digi-key | 399-9019-1-ND | $0.31 | $1.24 | 0603 SMD |  | Lead Free | RoHS Compliant | CAP CER 18PF 25V C0G/NP0 0603
25 | C13 | 1 | 3.3uF 0805 SMD capacitor | Kemet | C0805C335K9PACTU | Digi-key | 399-3130-1-ND | $0.60 | $0.60 | 0805 SMD |  | Lead Free | RoHS Compliant | CAP CER 3.3UF 6.3V X5R 0805
26 | R1 | 1 | 12kOhm 0603 SMD resistor | Panasonic | ERJ-3GEYJ123V | Digi-key | P12KGCT-ND | $0.10 | $0.10 | 0603 SMD |  | Lead Free | RoHS Compliant | RES SMD 12K OHM 5% 1/10W 0603
27 | R2 | 1 | 1kOhm 0603 SMD resistor | Panasonic | ERJ-3GEYJ102V | Digi-key | P1.0KGCT-ND | $0.10 | $0.10 | 0603 SMD |  | Lead Free | RoHS Compliant | RES SMD 1K OHM 5% 1/10W 0603
28 | R3 | 1 | 4.7kOhm 0603 SMD resistor | Panasonic | ERJ-3GEYJ472V | Digi-key | P4.7KGCT-ND | $0.10 | $0.10 | 0603 SMD |  | Lead Free | RoHS Compliant | RES SMD 4.7K OHM 5% 1/10W 0603
29 | R4, R6-R8 | 4 | 10kOhm 0603 SMD resistor | Panasonic | ERJ-3GEYJ103V | Digi-key | P10KGCT-ND | $0.10 | $0.40 | 0603 SMD |  | Lead Free | RoHS Compliant | RES SMD 10K OHM 5% 1/10W 0603
30 | R9 | 1 | 2.2kOhm 0603 SMD resistor | Panasonic | ERJ-3GEYJ222V | Digi-key | P2.2KGCT-ND | $0.10 | $0.10 | 0603 SMD |  | Lead Free | RoHS Compliant | RES SMD 2.2K OHM 5% 1/10W 0603
31 | R10-R28 | 19 | 12kOhm 0603 SMD resistor | Panasonic | ERJ-3GEYJ620V | Digi-key | P62GCT-ND | $0.10 | $1.90 | 0603 SMD |  | Lead Free | RoHS Compliant | RES SMD 62 OHM 5% 1/10W 0603

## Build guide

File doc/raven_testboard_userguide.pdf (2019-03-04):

J2: Flash CS select

UART display: Connect to display. Pin 1 = 3.3V, Pin 2 = GND, Pin 3 = Rx

Due to a board layout error, the intended functions are not as labeled.
J12 left is 8MHz CMOS clock
J3 left is 8MHz CMOS disable

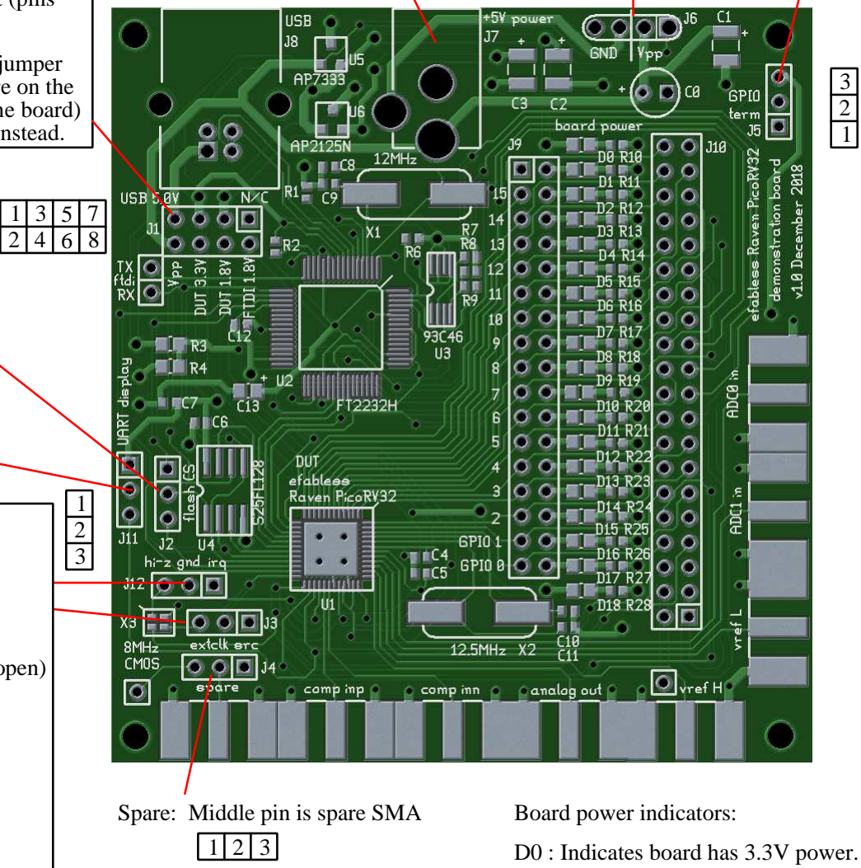
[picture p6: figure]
Spare: Middle pin is spare SMA; Board power indicators:

(ground to disable clock. Runs when open) J3 center pin is Raven Extclk input
J3 right pin goes to J10 ext. clk pin.
J12 right is Raven IRQ input.

Wire J12 left to J3 center to enable 8MHz clock to Raven Extclk input.

Wire J12 center to J3 left to silence the CMOS clock signal.

Jumpered at top:
FTDI accesses flash
(program mode)

Jumpered at bottom:
Raven accesses flash
(run-time mode)

DUT isolation points and
power connections:
A | B | C

Jumper A to power entire board from USB 5.0V (recommended) (pins 1–2)

Jumper B to power DUT 3.3V (normal operation). May be used as current measurement point (pins 3–4).

Jumper C to power DUT 1.8V. Normally DUT generates its own 1.8V output. Use this only as a backup or voltage test measurement point (pins 5–6).

Power jack: 5 to 6V input
(regulated)

4-pin power post:
5V input (regulated).

Only use one of these three power sources: Power jack, 4-pin power post, or USB 5V.

GPIO termination.
When GPIO lines are
connected across J9,
each GPIO drives an
LED.
Connected at top,
disables LEDs for
current measurements.

Connected at bottom,
LED lights when
GPIO output is low
(normal position).

Board power indicators only function when this is jumpered in the bottom position.

D0 : Indicates board has 3.3V power.
D18: Indicates Raven chip has 3.3V power.

Board rev v1.0 errata:

1. Accidental therm put on 4-pin header pin 1, ties Vpp to ground. Therm should be reamed out from ground on the board bottom side.
2. Device AP2125N has the wrong pinout. Device AP7333-18 should be used instead for U6. Device marked AP7333 (U5) is an AP7333-33 (3.3V output).
3. 8MHz CMOS footprint is inverted. Device was rotated to match the power and ground pins. The other two pins (clock and disable) are connected only through jumpers, so the only consequence is that the silkscreen names do not match.

Circuit board rev v1.0.

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
## efabless Raven test board User Manual

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
To program, connect pins 4 and 8 with a jumper wire. It may be preferable to solder a wire on the back between pins 4 and 7 (7 is N/C on the board) so that a jumper from 7 to 7 can be used instead.

Additional notes:
1. Device U6 is optional and should not be installed (Raven does not need additional 1.8V external supply).
2. Device U3 is optional. It can be used to prevent the board from appearing to the host computer as a serial device.
3. Due to lack of disable signals on the flash SPI pins during reset, the Raven chip must be put in a semi-powered-down state to access the flash from a host computer for flash programming. This is accomplished by powering the Raven chip at 1.8V from the FTDI 1.8V output.

May be used with jumper wire to connect any GPIO pin to the spare SMA connector.

## Board configurations:

## 1. Programming mode

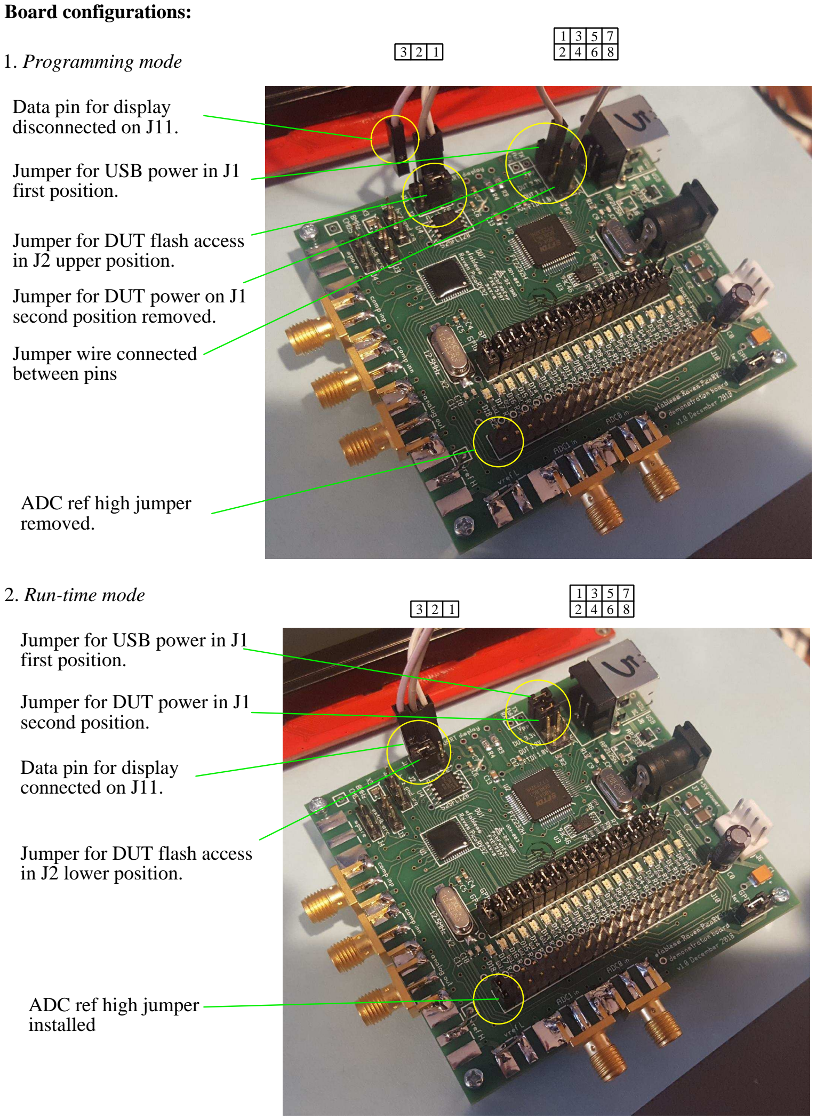
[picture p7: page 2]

## 2. Run-time mode

## Jumper for USB power in J1

first position.

## Jumper for DUT power in J1

second position.

## Jumper for DUT flash access

in J2 lower position.

## ADC ref high jumper installed

## Data pin for display

connected on J11.

## Jumper for USB power in J1

first position.

## Jumper for DUT power on J1

second position removed.

## Jumper for DUT flash access

in J2 upper position.

## ADC ref high jumper

removed.

## Data pin for display

disconnected on J11.

## Jumper wire connected between pins

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
## Programming the Raven:

## Getting the driver software: Driver software is tclftdi-1.0. Obtain from http://opencircuitdesign.com/tclftdi

## Git repo: use git clone git://opencircuitdesign.com/tclftdi-1.0

Install according to instructions. Prerequisite packages are tcl-dev, tk-dev, and libftdi-dev (for Ubuntu apt-get; yum equivalents are tcl-devel, tk-devel, and libftdi-devel).

## Obtain tclftdi scripts from the Raven standalone repo on github:

## git clone https://github.com/efabless/raven-picorv32

The tclftdi scripts can be found in the test/ subdirectory.

## Script startup_flash.tcl is for programming the SPI flash device:

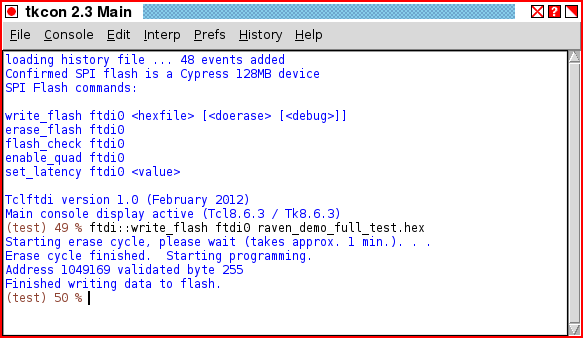
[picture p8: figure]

## Script startup_raven.tcl is for accessing the Raven housekeeping SPI:

## The board must be configured to

programming mode (see last page).

## The board must be configured to

run-time mode (see last page).

## Misconfiguration will result in failure to confirm the device, and immediate exit from

tclftdi.

## Misconfiguration will result in failure to confirm the device, and immediate exit from

tclftdi.

Available commands are printed on startup.

## The main command needed is "write_flash"

to write a hex file to the SPI flash.

## The file raven_demo_full_test.hex is an example demonstration program. For the source, see the git repo directory verilog/raven_demo/

Available commands are printed on startup.

## These commands are not necessary to run a program on the Raven but may be used for testing reset, external IRQ, setting the system clock to the external clock source, adjusting

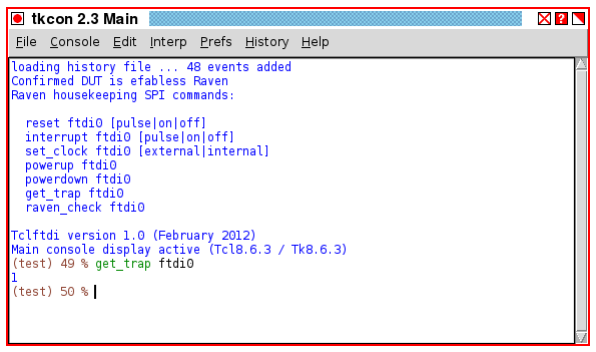
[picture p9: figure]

the PLL frequency (trim), enabling and disabling the crystal oscillator and voltage regulators, and reading the state of the PicoRV32 "trap" signal.

Raspberry-Pi compatibility GPIO header (3.3V)

5V

5V

From USB or power jack

VDD3V3

N/C (I2C)

N/C (I2C) | Ground
| TX
| RX

EXTCLK

Ground

GPIO0 | GPIO1

GPIO2

GPIO3

VDD3V3

SDI

SDO

SCK

Ground

Ground

CSB (Raven)

N/C (2nd SPI CSB)

N/C (I2C EEPROM)

Ground

Ground

Ground

Ground

GPIO4

GPIO5

GPIO6

GPIO7

GPIO8

GPIO9

GPIO10

GPIO11

GPIO13

GPIO14

GPIO15

GPIO12

N/C (I2C EEPROM)

NOTES:
Generally, the GPIO line up with similar channels on the Raspberry Pi board. The GCLK on the Pi is connected to the Raven external clock input. The I²C lines are not connected. The Raven SPI is connected to the Pi SPI lines.

## Raven external connector:

## The Raven test board is equipped with an external connector that matches the Raspberry Pi connector pinout, and allows the Raven chip to be used with Raspberry Pi compatible

daughterboards.

Note that some functions are not precisely equivalent to the Raspberry Pi functions. There is no
I

2C module on the Raven, so the I²C pins are no-connects. There is no I²C-compatible non-volatile memory on the Raven test board, so the EEPROM pins are no-connects. The 5V supply is also a no-connect but can be wired to the USB power supply if needed (note that the rev 1.0 test boards were all modified to use the 5V pin to connect to the VrefH analog input to VDD3V3 to avoid the need for external supplies to set the ADC and DAC reference voltages, so these pins are unavailable for use as a 5V supply connection). The SPI signals connect to the Raven housekeeping SPI and so are not available for use as an SPI master. The TX and RX lines connect to the Raven UART.

1 | 2
3 | 4
5 | 6
7 | 8
9 | 10
11 | 12
13 | 14
15 | 16
17 | 18
19 | 20
21 | 22
23 | 24
25 | 26
27 | 28
29 | 30
31 | 32
33 | 34
35 | 36
37 | 38
39 | 40

The lack of I²C means that some Raspberry Pi modules like the RTC cannot be used.

## Raven demonstration board, block diagram

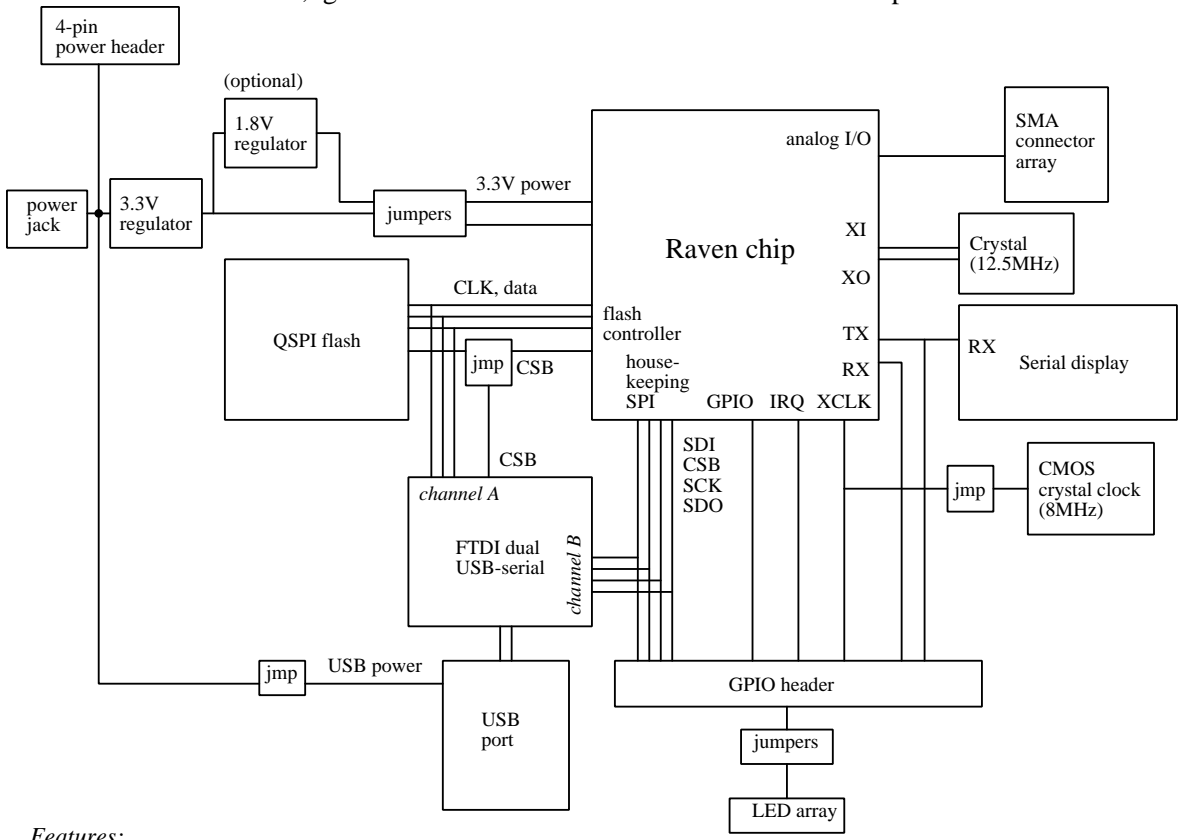
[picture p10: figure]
Raven chip; Serial display; FTDI dual USB-serial; SDI CSB SCK SDO; GPIO header; GPIO; USB port; QSPI flash; CSB; CLK, data; jumpers; LED array; IRQ XCLK; CMOS crystal clock (8MHz); Crystal (12.5MHz); jumpers power jack; 4-pin power header; 3.3V regulator; 3.3V power; regulator; analog I/O; SMA connector array; jmp; USB power; house- keeping SPI; flash controller; (optional); channel A; channel B

### Features:

1. Can be powered from external supplies, power jack, or USB.
2. Split supplies if external 1.8V needed; otherwise chip is powered from 3.3V only.

### 3. Flash chip programmed through FTDI via USB or from SPI header* 4. Raven SPI programmed through FTDI via USB 5. Serial display for text I/O from Raven chip 6. Clock from crystal (100MHz onboard), external (8MHz) or data line (slow) 7. Match Raspberry Pi header pins with GPIO header pins

SPI flash: Cypress S25FL128 or similar (available from Digi-Key).
Use the 8-pin SOIC (4 data + clock, select, power, and ground). 3.3V.

### FTDI: Use FT2232H (LQFP package)

### Serial display: Use a SparkFun serial-enabled 16x2 LCD, 3.3V, or the

20x4 SerLCD (available from Digi-Key). Or the 20x2 SerLCD.

## Obtain PCB layout from the Raven standalone repo on github:

## git clone https://github.com/efabless/raven-picorv32

## The layout can be found in the pcb/ subdirectory. Layout is in gEDA "pcb"

format; gerber files are also available. See BOM for complete bill of materials.

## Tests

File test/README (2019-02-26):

Raven functional validation
----------------------------------------------
This test system uses tclftdi 1.0
(http://opencircuitdesign.com/tclftdi/)

------------------------------------------------------------
To program the SPI flash chip:

  1. Configure the board for flash programming.

      For test board v1.1:
      A. Move jumper J1 2nd position (DUT 3.3V) to 4th position (FTDI 1.8V)
      B. Move jumper J2 bottom position (pins 2-3) to top position (pins 1-2)
      C. Preferably remove the data connection to the display.

  2. In this directory, run (as root)

      tclftdi startup_flash.tcl

  3. At the prompt, do:

      write_flash ftdi0 raven_demo_full_test.hex

  4. Configure the board for processor operation

      A. Move jumper J1 4th position (FTDI 1.8V) to 2nd position (DUT 3.3)
      B. Move jumper J2 position (pins 1-2) to bottom position (pins 2-3)
      C. Reconnect data connection to the display, if removed.

To communicate with the Raven housekeeping SPI:

  1. Configure the board for processor operation (see above)

  2. In this directory, run (as root)

      tclftdi startup_raven.tcl

  3. The tool will show the various commands that can be used
     to access and manipulate the Raven processor through the
     SPI interface.

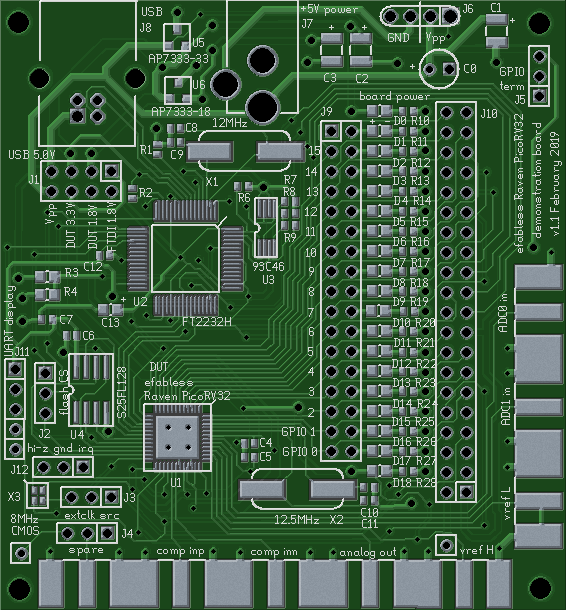
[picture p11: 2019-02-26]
pcb/raven_testboard.png

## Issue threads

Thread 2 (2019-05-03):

Where to buy this CPU ?

Martoni, 2019-05-03:
Is it possible to buy this proc and/or a devkit ?

RTimothyEdwards, 2019-05-03:
At the moment, no, because we had a limited number (50) of chips from the initial shuttle run and an even more limited number (5) of assembled development boards.  However, we are getting several hundred additional parts from the foundry that are currently in process.  Please contact support@efabless.com and ask to be informed when additional development boards are available.

Closed 2019-05-03.

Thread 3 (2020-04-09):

How to run the iverilog simulation without the voltage regulator ?

sofchet, 2020-04-09:
Hi,
I am trying to run the iverilog simulation of the Raven-picorv32, however, as mentioned in your verilog code, iverilog does not support the aregc01_3v3 regulator module. What would be the best way to run the simulation without the regulator ?

Knowing that I am not interested in any analog part simulation, I need just an easy way to make sure that the SoC part is correctly working with the GPIOs.

I tried commenting the voltage regulator part and running the GPIO simulation, however, the GPIO states are not being reported correctly by the C program.

Many thanks

RTimothyEdwards, 2020-04-09:
iverilog does not support verilog-A or verilog-AMS.  However, the versions of the analog blocks that are in this repository are compatible with iverilog.  They use real-valued I/O for representing the power supplies, so it is possible to not only simulate, but also to check that the power supplies are correct in both the 1.8 and 3.3V domains.

sofchet, 2020-04-09:
Many thanks for your answer.

Actually when I try to run the make file for the raven_gpio simulation I get the following:

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

Which is related to the voltage regulator I told you about. It is actually mentioned in line 1603 in your code that there is some issue with the iverilog not supporting that module.

Then when I comment the module and run the simulation I don't get the right GPIO output:

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

Can you please tell what would be the best way to run your tests, with the fewest edits possible ?

thanks,

RTimothyEdwards, 2020-04-09:
Ah, it does look like raven.v is missing one important correction.  iverilog will not connect two real valued outputs, so having two voltage regulators with the output tied to the same net won't work.  The (hack) workaround that I used was to remove the array identifier [1:0] from the voltage regulator (see raven.v line 1602).  For purposes of getting correct LVS, I instantiated the voltage regulator twice and put one of them inside an "`ifdef LVS ... `endif" block so that it was not seen by the simulator.

Of course, any time that something is hidden from the simulator is a possible place to introduce an error that isn't seen in simulation.  For the moment, I don't have a better workaround, though.

---Tim

RTimothyEdwards, 2020-04-09:
Note that the "ifdef" and "endif" above were supposed to have verilog back-ticks.  However, the stupid markup language for this page uses back-ticks to denote code, thus denying the possibility that code can have back-ticks, which is utterly stupid.  There may be an alternative markup, but I don't know what it is.

sofchet, 2020-04-09:
okay many thanks ! it worked

Closed 2020-04-09.

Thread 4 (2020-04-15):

Adding an SPI Master to the Raven SoC

sofchet, 2020-04-15:
Hi,

I want to add an SPI interface to the SoC (hardware level) to communicate with any SPI slave interface.
I guess the SPI interfaces that already exist in the Raven design are for other purposes. So I was wondering what would be the best approach to integrate an SPI master interface to the design ? For instance, in case I don't need the Raven_SPI, do you think I can easily just turn it to a general purpose SPI interface ?

Thanks,

RTimothyEdwards, 2020-04-15:
I added several components to an update of the Raven chip called Ravenna which we taped out mid-year last year, got back at the end of last year, and have already tested and mostly validated (there were other priorities in the way;  the last bit of testing should get done in the next few weeks some time).  The new components include the SPI master you're looking for, as well as an I2C master, and a counter/timer module.

To get those modules, see github.com/efabless/ravenna.  You can either use the Ravenna project as a base (it is very similar to Raven;  essentially just an expanded version of Raven), or copy the SPI master module into your project.

Regards,
Tim

sofchet, 2020-04-15:
@RTimothyEdwards  many thanks for your answer !.

However it seems like the verilog files are not shared yet on the /efabless/ravenna repo. Can you please tell me how can get them ?

I have a kind of related question, but I would open a new issue for it.

Thanks again

RTimothyEdwards, 2020-04-15:
Okay, sorry, I didn't realize that the Ravenna repo was only for design support (PCB, assembly, test).  The RTL is available on the efabless.com platform (marketplace catalog).  I'm not sure how easy it is to get the RTL off the platform, though.  It may require some cut-and-paste.

sofchet, 2020-04-15:
Thanks a million, I am closing this issue.

sofchet, 2020-04-15:
Sorry probably this is not the best place to ask this question, but I got my account review completed and I was granted the full access, however, I am not sure how to get the RTL from the marketplace catalog. On the Ravenna page there seem to be no link that leads to the RTL files.

Should I submit some inquiry ?
Thanks,

RTimothyEdwards, 2020-04-15:
No problem asking here. . . So from the Dashboard go to the Marketplace, click on the "SoC Platform" tab (the default, I think), and then click on "Ravenna".  On that page, below the block diagram, is a button "Add Soft IP".  Click that, and enter a project name in the pop-up window or accept the default.  A message appears at the top with a link to "Soft Projects" (that you can also reach from the Dashboard).  Go to the "Soft Projects" page and find the project listed there.  On the same line as the project name, there are a number of buttons including one labeled "CloudV".  Click that one.  In the CloudV environment, the SPI master can be found under source/simple_spi_master.v.  From there, I am not entirely sure of the proper method for copy and paste;  there are several menu items under Edit in CloudV (and none of them works with my setup, but I'm using a very old and uncommon window manager under Linux).

sofchet, 2020-04-24:
@RTimothyEdwards  Many thanks, I was able to integrate the SPI Master from the Ravenna design to the Raven design and perform some simulation.

Based on the simulation waves it seems like the SPI Master is configured to read only 1 Byte at once, for instance the spi_sck coming from the master is right way shut down after 8 periods.

I was wondering what would be the necessary edits to make to be able to write/read 256 bits (32 bytes) at once, with no gaps in between ?

Am I only supposed to edit the state transition verilog part :
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

where the edit consists in transitioning to the finish state after 255 counts, rather than the 7 counts set through the nbit register.

Or there are much more things into it ?

Thanks

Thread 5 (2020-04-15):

Is the Raven SPI functionnal ?

sofchet, 2020-04-15:
Hi,

I was wondering whether the Raven_SPI was tested ? and in case it is not needed, what would be the safe way to get rid of the Raven_SPI without hurting the design ?

Thanks,

RTimothyEdwards, 2020-04-15:
The SPI in the Raven chip is considered a "housekeeping" SPI.  It was designed largely to keep a number of critical functions away from the processor itself and allow for more convenient testing.  Mostly this was deemed necessary because Raven was a first-of-its-kind proof of concept.  In case anything was wrong with the design, I wanted multiple ways to access the chip and see what was going on.  As it turned out, the Raven chip worked perfectly well.  So, the short answer is that there is nothing mandatory about the housekeeping SPI.  If you remove it, just make sure that the critical components it touches (like the PLL, the crystal oscillator, voltage references, etc.) are hard-wired to the right values (i.e., enabled), or memory-mapped into the processor area, with the correct defaults.  If you memory-map any of those signals, watch for the ones that will self-destruct;  e.g., turning off the voltage regulator will instantly kill the processor.

If you are looking at the RTL for the Ravenna design on efabless.com, note that the housekeeping SPI there has an additional useful function called "pass-through" mode, which allows the housekeeping SPI to be used to access the SPI flash chip.  That allows the SPI flash chip to be connected solely to the processor, without the need to jumper between the processor and the FTDI chip when switching between flash programming and application run-time.

Another option I have considered but never implemented is to keep the housekeeping SPI, but let the SPI signals be shared with GPIO.  Any program would then be able to disable the SPI communication and make use of the GPIO pins for other purposes.

Regards,
Tim

sofchet, 2020-04-15:
Oh okay I see, thanks for the detailed and clear answer !

Closed 2020-04-15.

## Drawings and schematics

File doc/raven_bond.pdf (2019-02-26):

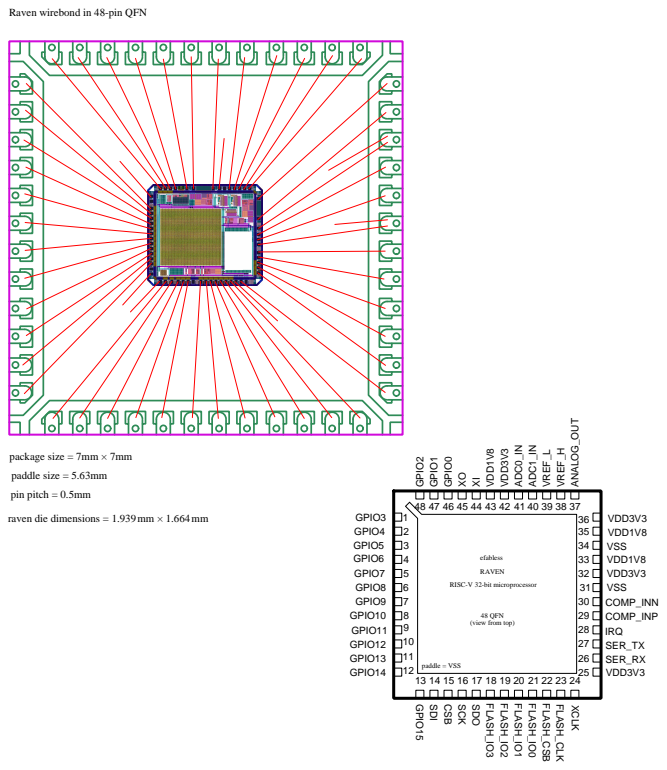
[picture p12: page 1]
RAVEN; paddle = VSS 12; GPIO3; GPIO2; GPIO1; GPIO0; VDD1V8; VDD3V3; ADC0_IN; ADC1_IN; VREF_L; VREF_H; ANALOG_OUT; SER_RX; VSS VDD1V8; COMP_INP; SER_TX; VSS COMP_INN; IRQ; GPIO15; SDI; CSB; SCK; SDO; FLASH_IO3; FLASH_IO2; FLASH_IO1; FLASH_IO0; FLASH_CSB; FLASH_CLK; XCLK; GPIO4 GPIO5 GPIO6 GPIO7 GPIO8 GPIO9 GPIO10 GPIO11 GPIO12 GPIO13 GPIO14; efabless; paddle size = 5.63mm pin pitch = 0.5mm; package size = 7mm × 7mm

Raven wirebond in 48-pin QFN

raven die dimensions = 1.939mm × 1.664mm

RISC-V 32-bit microprocessor

48 QFN
(view from top)

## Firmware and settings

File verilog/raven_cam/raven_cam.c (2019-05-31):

#include "../raven_defs.h"
#include "cam.h"
#include "spi_io.h"
#include "i2c_io.h"


#define BCD_DIGIT0(x) (x & (uint32_t)0x000F)
#define BCD_DIGIT1(x) ((x >> 4) & (uint32_t)0x000F)

volatile uint32_t counter;
volatile uint32_t counter2 = 100;


// --------------------------------------------------------
// Firmware routines
// --------------------------------------------------------

// Copy the flash worker function to SRAM so that the SPI can be
// managed without having to read program instructions from it.

void flashio(uint32_t *data, int len, uint8_t wrencmd)
{
	uint32_t func[&flashio_worker_end - &flashio_worker_begin];

	uint32_t *src_ptr = &flashio_worker_begin;
	uint32_t *dst_ptr = func;

	while (src_ptr != &flashio_worker_end)
		*(dst_ptr++) = *(src_ptr++);

	((void(*)(uint32_t*, uint32_t, uint32_t))func)(data, len, wrencmd);
}

//--------------------------------------------------------------
// NOTE: Volatile write *only* works with command 01, making the
// above routing non-functional.  Must write all four registers
// status, config1, config2, and config3 at once.
//--------------------------------------------------------------
// (NOTE: Forces quad/ddr modes off, since function runs in single data pin mode)
// (NOTE: Also sets quad mode flag, so run this before entering quad mode)
//--------------------------------------------------------------

void set_flash_latency(uint8_t value)
{
	reg_spictrl = (reg_spictrl & ~0x007f0000) | ((value & 15) << 16);

	uint32_t buffer_wr[2] = {0x01000260, ((0x70 | value) << 24)};
	flashio(buffer_wr, 5, 0x50);
}

//--------------------------------------------------------------

void flash_led(int led, bool on)
{
    uint32_t pin = (1 << led);
    reg_gpio_ena &= ~(pin);

    if (on)
        reg_gpio_data |= pin;
    else
        reg_gpio_data &= ~(pin);

}

void putchar(char c)
{
	if (c == '\n')
		putchar('\r');
	reg_uart_data = c;
}

void send_serial(uint32_t c)
{
	reg_uart_data = c;
}

void print(const char *p)
{
	while (*p)
		putchar(*(p++));
}

void print_ln(const char *p)
{
	for (int i=0; i<20; i++)
	{
	    if (*p)
		    putchar(*(p++));
        else
		    putchar(' ');
    }
}

void clear()
{
    reg_uart_data = 0x7c;
    reg_uart_data = 0x2d;
}

void home()
{
    reg_uart_data = 254;
    reg_uart_data = 0x02;
}

void print_hex(uint32_t v, int digits)
{
	for (int i = digits - 1; i >= 0; i--) {
		char c = "0123456789abcdef"[(v >> (4*i)) & 15];
		putchar(c);
	}
}

void print_dec(uint32_t v)
{
	if (v >= 2000) {
		print("OVER");
		return;
	}
	else if (v >= 1000) { putchar('1'); v -= 1000; }
	else putchar(' ');

	if 	(v >= 900) { putchar('9'); v -= 900; }
	else if	(v >= 800) { putchar('8'); v -= 800; }
	else if	(v >= 700) { putchar('7'); v -= 700; }
	else if	(v >= 600) { putchar('6'); v -= 600; }
	else if	(v >= 500) { putchar('5'); v -= 500; }
	else if	(v >= 400) { putchar('4'); v -= 400; }
	else if	(v >= 300) { putchar('3'); v -= 300; }
	else if	(v >= 200) { putchar('2'); v -= 200; }
	else if	(v >= 100) { putchar('1'); v -= 100; }
	else putchar('0');
		
	if 	(v >= 90) { putchar('9'); v -= 90; }
	else if	(v >= 80) { putchar('8'); v -= 80; }
	else if	(v >= 70) { putchar('7'); v -= 70; }
	else if	(v >= 60) { putchar('6'); v -= 60; }
	else if	(v >= 50) { putchar('5'); v -= 50; }
	else if	(v >= 40) { putchar('4'); v -= 40; }
	else if	(v >= 30) { putchar('3'); v -= 30; }
	else if	(v >= 20) { putchar('2'); v -= 20; }
	else if	(v >= 10) { putchar('1'); v -= 10; }
	else putchar('0');

	if 	(v >= 9) { putchar('9'); v -= 9; }
	else if	(v >= 8) { putchar('8'); v -= 8; }
	else if	(v >= 7) { putchar('7'); v -= 7; }
	else if	(v >= 6) { putchar('6'); v -= 6; }
	else if	(v >= 5) { putchar('5'); v -= 5; }
	else if	(v >= 4) { putchar('4'); v -= 4; }
	else if	(v >= 3) { putchar('3'); v -= 3; }
	else if	(v >= 2) { putchar('2'); v -= 2; }
	else if	(v >= 1) { putchar('1'); v -= 1; }
	else putchar('0');
}

void print_digit(uint32_t v)
{
    v &= (uint32_t)0x000F;

    if (v == 9) { putchar('9'); }
    else if (v == 8) { putchar('8'); }
    else if (v == 7) { putchar('7'); }
    else if (v == 6) { putchar('6'); }
    else if (v == 5) { putchar('5'); }
    else if (v == 4) { putchar('4'); }
    else if (v == 3) { putchar('3'); }
    else if (v == 2) { putchar('2'); }
    else if (v == 1) { putchar('1'); }
    else if (v == 0) { putchar('0'); }
    else putchar('*');
}

char getchar_prompt(char *prompt)
{
	int32_t c = -1;

	uint32_t cycles_begin, cycles_now, cycles;
	__asm__ volatile ("rdcycle %0" : "=r"(cycles_begin));


	if (prompt)
		print(prompt);

	while (c == -1) {
		__asm__ volatile ("rdcycle %0" : "=r"(cycles_now));
		cycles = cycles_now - cycles_begin;
		if (cycles > 12000000) {
			if (prompt)
				print(prompt);
			cycles_begin = cycles_now;
		}
		c = reg_uart_data;
	}

	return c;
}

char getchar()
{
	return getchar_prompt(0);
}

// ----------------------------------------------------------------------

void cmd_read_flash_regs_print(uint32_t addr, const char *name)
{
    uint32_t buffer[2] = {0x65000000 | addr, 0x0}; //
    flashio(buffer, 6, 0);

    print("0x");
    print_hex(addr, 6);
    print(" ");
    print(name);
    print(" 0x");
    print_hex(buffer[1], 2);
    print("  ");
}

void cmd_echo()
{
	print("Return to menu by sending '!'\n\n");
	char c;
	while ((c = getchar()) != '!') {
		if (c == '\r')
		    putchar('\n');
        else
		    putchar(c);
    }
}

// ----------------------------------------------------------------------

void cmd_read_flash_regs()
{
    cmd_read_flash_regs_print(0x800000, "SR1V");
    cmd_read_flash_regs_print(0x800002, "CR1V");
    cmd_read_flash_regs_print(0x800003, "CR2V");
    cmd_read_flash_regs_print(0x800004, "CR3V");
}

void rtc_run()
{
    write_i2c_slave(RTC_I2C_ADDR, 0x00, 0x00);
}

void rtc_stop()
{
    write_i2c_slave(RTC_I2C_ADDR, 0x00, 0x10);
}

void read_rtc()
{
    uint32_t data[2];

//    data = read_i2c_slave_byte(RTC_I2C_ADDR, 0x00); // RTC DS3231

    read_i2c_slave_bytes(RTC_I2C_ADDR, 0x02, data, 3); // RTC PCF8563

    data[0] &= (uint32_t) 0x007F;
    data[1] &= (uint32_t) 0x007F;
    data[2] &= (uint32_t) 0x003F;

//    print("\r");
    print("Time = ");
    print_digit(BCD_DIGIT1(data[2]));
    print_digit(BCD_DIGIT0(data[2]));
    print(":");
    print_digit(BCD_DIGIT1(data[1]));
    print_digit(BCD_DIGIT0(data[1]));
    print(":");
    print_digit(BCD_DIGIT1(data[0]));
    print_digit(BCD_DIGIT0(data[0]));
    print("     ");
    print("\n\n");

}

void display_counter()
{
    print("counter = ");
    print_dec(counter);
    print("\n");

    print("counter2 = ");
    print_dec(counter2);
    print("\n");
}

// ----------------------------------------------------------------------
// Raven demo:  Demonstrate various capabilities of the Raven testboard.
//
// 1. Flash:  Set the flash to various speed modes
// 2. GPIO:   Drive the LEDs in a loop
// 3. UART:   Print text to the UART LCD display
// 4. RC Osc: Enable the 100MHz RC oscillator and output on a GPIO line
// 5. DAC:    Enable the DAC and ramp
// 6. ADC:    Enable both ADCs and periodically read and display the DAC
//	      and bandgap values on the UART display.
// ----------------------------------------------------------------------
// NOTE:  There are two versions of this demo.  Demo 1 runs only up to
//	  2X speed (DSPI + CRM).  The higher speeds cause some timing
//	  trouble, which may be due to reflections on the board wires
//	  for IO2 and IO3.  Not sure of the mechanism.  To keep the
//	  boards running without failure, do not use QSPI modes.

void main()
{
	uint32_t i, j, m, r, mode;
	uint32_t adcval;
	uint32_t dacval;
	uint32_t data, data2, fifo_size, length, last_data;
	char k;
	bool is_header;

	counter = 0;

	/* Note that it definitely does not work in simulation because	*/
	/* the behavioral verilog for the SPI flash does not support	*/
	/* the configuration register read/write functions.		*/

	set_flash_latency(8);
	reg_spictrl = 0x80080000;

	m = 1;

    // disable all pull-up and pull-down gpio resistors
	reg_gpio_pu = 0xffff;
	reg_gpio_pd = 0xffff;

	// NOTE: Crystal on testboard running at 12.5MHz
	// Internal clock is 8x crystal, or 100MHz
	// Divided by clkdiv is 9.6 kHz
	// So at this crystal rate, use clkdiv = 10417 for 9600 baud.

	// Set UART clock to 9600 baud
	reg_uart_clkdiv = 10417;


	// Need boot-up time for the display;  give it 4 seconds
	for (j = 0; j < 700000 * m; j++);

	// This should appear on the LCD display 4x20 characters.
    print("Starting...\n");
    i2c_init();
    spi_init();

    print("Press ENTER to continue..\n");
    while (getchar() != '\r') {}

    print("\n\n");

	int led_a = 6;
	int led_b = 7;

    // test spi with write and read from test register
    if (check_spi()) {
        print("SPI communication successful.\n");
    } else {
        print("SPI communication FAILED!\n");
    }

    // test if camera is present
    uint32_t vid, pid;
    if (check_camera(&vid, &pid)) {
        print("Camera Located (");
    } else {
        print("Camera NOT FOUND (");
    }
    print("vid = 0x");
    print_hex(vid,2);
    print(", pid = 0x");
    print_hex(pid,2);
    print(")\n");

	// reset CPLD
//	reset_cpld();

//	init_camera();
//	if (!set_JPEG_size(OV2640_320x240))
//	    print("set_JPEG_size FAILED!\n");

//    for (j = 0; j < 170000; j++); // 1 sec delay
//    set_frame_count();



	while (1) {

        k = getchar();

        counter++;
        counter2++;

        switch(k) {
            case'0':
                print("initialize camera...\n");
            	reset_cpld();
                init_camera();
                for (j = 0; j < 170000; j++); // 1 sec delay
//                set_frame_count();
                break;
            case'1':
                print("clear FIFO...\n");
                flush_fifo();
                clear_fifo_flag();
                break;
            case'2':
                print("triggering capture...\n");
                flash_led(led_a, true); flash_led(led_b, false);

                // reset FIFO and flag
                flush_fifo();
                clear_fifo_flag();

                // trigger capture
                start_capture();

                // wait for status
                i = 0;
                while (i < 100) {
                    data = read_spi_slave_byte(0x41);
                    if (data & 0x08) {
                        break;
                    }
                    i++;
                  if (i == 100)
                        print("Error - capture flag not found.\n");
                };

                flash_led(led_a, false); flash_led(led_b, true);
                break;
            case '3':
                print("reading FIFO register length...\n");
                fifo_size = read_fifo_length();
                print("   ");
                print("0x"); print_hex(fifo_size, 6);
                print("\n");
                break;
            case '4':
                print("reading registers...\n");

                data = read_spi_slave_byte(0x01);
                print("   ");
                print("0x"); print_hex(data, 2);

                data = read_spi_slave_byte(0x40);
                print("   ");
                print("0x"); print_hex(data, 2);

                data = read_spi_slave_byte(0x42);
                print("   ");
                print("0x"); print_hex(data, 2);

                data = read_spi_slave_byte(0x43);
                print("   ");
                print("0x"); print_hex(data, 2);

                data = read_spi_slave_byte(0x44);
                print("   ");
                print("0x"); print_hex(data, 2);

                print("\n");
                break;
            case '5':
                print("display FIFO data (next 80 values)...\n");

                for (i=0; i<20; i++) {
                    for (j=0; j<20; j++) {
                        data = read_spi_slave_byte(0x3D);
                        print("  ");
                        print_hex(data, 2);
                    }
                    print("\n");
                }
                break;
            case '6':
                print("resetting FIFO read pointer\n");
                reset_fifo_read_ptr();
                break;
            case '7':
                reset_fifo_read_ptr();
                fifo_size = read_fifo_length();
                data = read_spi_slave_byte(FIFO_SIZE1); send_serial(data);
                data = read_spi_slave_byte(FIFO_SIZE2); send_serial(data);
                data = read_spi_slave_byte(FIFO_SIZE3); send_serial(data);
                send_serial(0xff);
                length = fifo_size;
                is_header = false;
                data = read_spi_slave_byte(0x3D);
                length--;
                while (length--) {
                    last_data = data;
                    data = read_spi_slave_byte(0x3D);
                    if (is_header == true)
                        send_serial(data);
                    else if ((data == 0xd8) && (last_data == 0xff)) {
                        is_header = true;
                        send_serial(last_data);
                        send_serial(data);
                    }
                    if ((data == 0xd9) && (last_data == 0xff))
                        break;
                }
                print("transfer complete.\n");
                break;
            case '8':
                print("setting JPEG size to 160x120\n");
                if (!set_JPEG_size(OV2640_160x120))
	                print("set_JPEG_size FAILED!\n");
                break;
            case '9':
                print("setting JPEG size to 320x240\n");
                if (!set_JPEG_size(OV2640_320x240))
	                print("set_JPEG_size FAILED!\n");
                break;
            case 'c':
                print("read real-time clock...\n");
                read_rtc();
                break;
            case 'g':
                print("display loop counter...\n");
                display_counter();
                break;

            default:
                print("menu:\n");
                print("[0] initialize camera\n");
                print("[1] clear FIFO\n");
                print("[2] trigger capture\n");
                print("[3] read FIFO length registers\n");
                print("[4] read registers\n");
                print("[5] display FIFO data (next 80 values)\n");
                print("[6] reset FIFO read pointer\n");
                print("[7] transfer FIFO data\n");
                print("[8] set JPEG size to 160x120\n");
                print("[9] set JPEG size to 320x240\n");
                print("[c] read real-time clock\n");
                print("[g] display loop counter\n");
                print("[q] quit serial client\n");
                break;
        }

        for (j = 0; j < 170000; j++); // 1 sec delay

	}
}

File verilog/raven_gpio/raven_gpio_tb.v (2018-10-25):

/*
 *  Raven - A full example SoC using PicoRV32 in X-Fab XH018
 *
 *  Copyright (C) 2017  Clifford Wolf <clifford@clifford.at>
 *  Copyright (C) 2018  Tim Edwards <tim@efabless.com>
 *
 *  Permission to use, copy, modify, and/or distribute this software for any
 *  purpose with or without fee is hereby granted, provided that the above
 *  copyright notice and this permission notice appear in all copies.
 *
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
 */

`timescale 1 ns / 1 ps

`include "../raven.v"
`include "../spiflash.v"

module raven_gpio_tb;
	reg XCLK;
	reg real VDD3V3;

	reg real XI;
	wire real XO;

	reg real adc_h, adc_l;
	reg real adc_0, adc_1;
	reg real comp_n, comp_p;
	wire real ana_out;

	always #100 XCLK <= (XCLK === 1'b0);
	always #50 XI = VDD3V3 - XO;

	initial begin
		XCLK <= 1'b0;
		XI = 0.0;
		#150;
		XI = VDD3V3 / 2 - 0.1;
	end

	initial begin
		// Ramp VDD3V3 from 0 to 3.3V
		VDD3V3 = 0.0;
		#50;
		repeat (33) begin
		   #3;
		   VDD3V3 = VDD3V3 + 0.1;
		end
	end

	initial begin
		// Analog input pin values

		adc_h = 0.0;
		adc_l = 0.0;
		adc_0 = 0.0;
		adc_1 = 0.0;
		comp_n = 0.0;
		comp_p = 0.0;
		#2000;
		adc_h = 3.25;
		adc_l = 0.05;
		adc_0 = 1.0;
		adc_1 = 1.5;
		comp_n = 2.0;
		comp_p = 2.5;
	end

	initial begin
		$dumpfile("raven_gpio.vcd");
		$dumpvars(0, raven_gpio_tb);

		// Only one cycle of 1000 clocks needed for testbench.
		repeat (1) begin
			repeat (1000) @(posedge XCLK);
			$display("+1000 cycles");
		end
		$finish;
	end

	wire [15:0] gpio;

	wire flash_csb;
	wire flash_clk;
	wire flash_io0;
	wire flash_io1;
	wire flash_io2;
	wire flash_io3;

	reg SDI, CSB, SCK;
	wire SDO;

	initial begin
		CSB <= 1'b1;
		SCK <= 1'b0;
		SDI <= 1'b0;
		#1000;
		CSB <= 1'b0;
	end

	always @(gpio) begin
		#1 $display("GPIO state = %b", gpio);
	end

	wire real VDD1V8;
	wire real VSS;

	assign VSS = 0.0;

	raven uut (
		.VDD3V3	  (VDD3V3  ),
		.VDD1V8	  (VDD1V8),
		.VSS	  (VSS),
		.XI	  (XI),
		.XO	  (XO),
		.XCLK	  (XCLK),
		.SDI	  (SDI),
		.SDO	  (SDO),
		.CSB	  (CSB),
		.SCK	  (SCK),
		.ser_rx	  (1'b0),
		.ser_tx	  (	    ),
		.irq	  (1'b0	    ),
		.gpio     (gpio     ),
		.flash_csb(flash_csb),
		.flash_clk(flash_clk),
		.flash_io0(flash_io0),
		.flash_io1(flash_io1),
		.flash_io2(flash_io2),
		.flash_io3(flash_io3),
		.adc_high (adc_h),
		.adc_low  (adc_l),
		.adc0_in  (adc_0),
		.adc1_in  (adc_1),
		.analog_out(ana_out),
		.comp_inp (comp_p),
		.comp_inn (comp_n)
	);

	spiflash #(
		.FILENAME("raven_gpio.hex")
	) spiflash (
		.csb(flash_csb),
		.clk(flash_clk),
		.io0(flash_io0),
		.io1(flash_io1),
		.io2(flash_io2),
		.io3(flash_io3)
	);

endmodule

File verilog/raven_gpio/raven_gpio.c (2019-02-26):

#include "../raven_defs.h"

// --------------------------------------------------------

void main()
{
    int i;

    /* Test : toggle the GPIO pins once as the first action */
    reg_gpio_pu = 0x5a5a;
    reg_gpio_ena =  0xa5a5;

    reg_gpio_data = 0xffff;
    reg_gpio_data = 0x0000;

    /* loop test: cycle all GPIO periodically; continue indefinitely */
    while (1) {
	for (i = 0 ; i < 100000000; i++);
        reg_gpio_data = 0xffff;
	for (i = 0 ; i < 100000000; i++);
	reg_gpio_data = 0x0000;
    }
}

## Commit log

2019-02-26 added pcb/test files and docs
    [raven_testboard_bom.xlsx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]
2019-03-11 update i2c bit bang and rtc demo
2019-03-16 rtc demo - debugging i2c
2019-04-14 raven_cam -- add spi camera demo
2019-04-14 raven_cam -- fix unsigned char -> uint32_t
    [raven_cam.c]
2019-04-15 raven_cam -- debug spi driver
2019-04-17 raven_cam -- testing camera trigger
2019-04-17 raven_cam -- test camera
2019-04-17 raven_cam -- testing camera spi interface
2019-05-01 raven_cam -- debugging camera image
2019-05-01 raven_cam -- debug camera images
2019-05-31 raven_cam -- fix global variables issue
    [cam.c, raven_cam.c]
2019-08-13 raven_adc - updated for raven2 board
2019-08-13 raven_rtc - support raven2 board + updated linker
2019-08-13 raven_demo - support raven2 board
